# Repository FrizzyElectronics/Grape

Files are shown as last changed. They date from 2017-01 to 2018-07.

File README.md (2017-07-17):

# Grape

frizzyelectronics (http://frizzy.es)

Grape es un Arduino&trade; compatible de fabricacion y diseño español. Destaca frente a otras placas por su rapidez de conexionado y por no necesitar el uso de protoboard para realizar los proyectos.

## Rasgos destacados

  - Conexion micro-USB
  - Corriente max de salida (5V) 2A
  - Pines de conexión rápida
  - Interruptor de encendido-apagado
  - 8 pines analogicos
  - Compatible con los shields de Arduino&trade; y con Arduino&trade; IDE

Frizzy Grape  

## Documentacion 

* **/Hardware** - Archivos de diseño en KiCad e Eagle, esquema en PDF
* **/Production** - Gerbers, BOM
* **/Design** - Logos, SVG 

Licencia
-------------------

Este producto es  **open source**! 

Por favor, revisa el archivo [LICENSE.md](https://github.com/FrizzyElectronics/Grape/blob/master/License.md) para más información. 

Si tiene alguna duda acerca del uso de esta licencia contatanos a traves de  info@frizzy.es

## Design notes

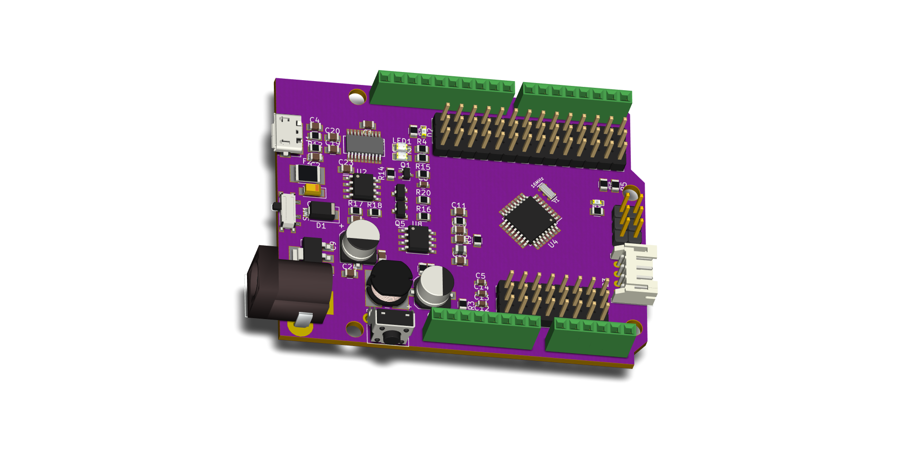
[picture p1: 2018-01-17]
Hardware/KiCad/images/Grape.png

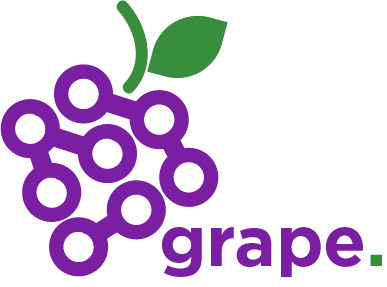
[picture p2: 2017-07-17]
Design/Frizzy Grape (color con texto).png

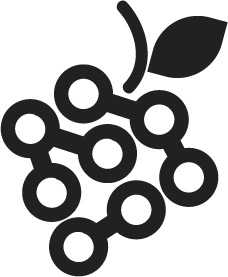
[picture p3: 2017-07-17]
Design/Frizzy Grape (negro sin texto).png

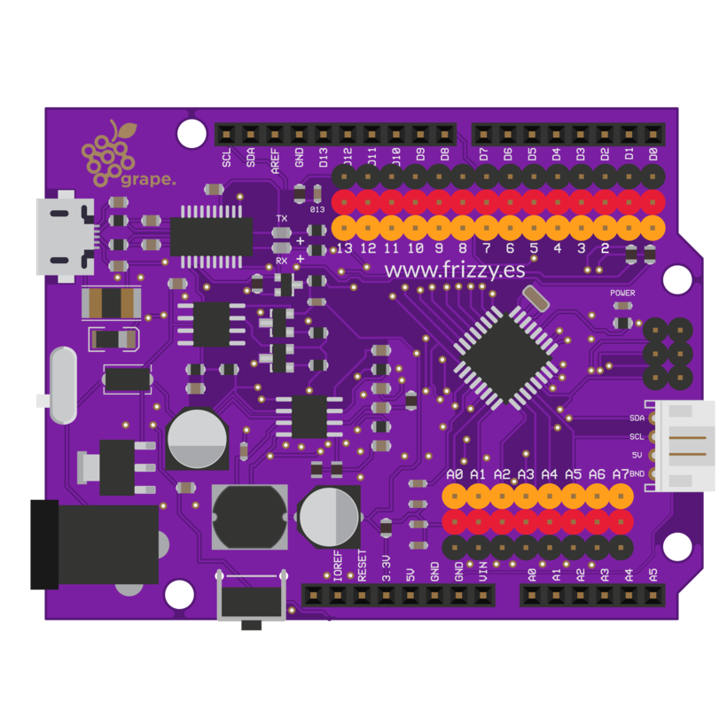
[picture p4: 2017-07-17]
Design/grape2-big.png

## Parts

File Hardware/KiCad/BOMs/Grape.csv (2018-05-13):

Id | Identificador | Empaquetado | Cantidad | Identificación | Suministrador y ref
1 | REF**,REF**,REF** | Fiducial_1mm_Dia_2mm_Outer | 3 | Fiducial_1mm_Dia_2mm_Outer
2 | J3 | ARDUINO_R3 | 1 | ARDUINO_R3
3 | REF*** | OSHW-Symbol_6.7x6mm_SilkScreen | 1 | OSHW-Symbol_6.7x6mm_SilkScreen
4 | C1,C2,C4,C10,C11,C15,C22,C23,C24 | C_0805 | 9 | 100nF
5 | C3 | CP_Tantalum_Case-A_EIA-3216-18_Reflow | 1 | 10nF
6 | C5,C6,C13 | C_0603 | 3 | 100nF
7 | C7,C9 | CP_Elec_6.3x5.3 | 2 | 100uF
8 | C8 | C_0805 | 1 | 3.3nF
9 | C12 | C_0603 | 1 | 1uF
10 | C14 | C_0603 | 1 | 10nF
11 | C16 | C_0805 | 1 | 10nF
12 | C19,C20 | C_0805 | 2 | 47pF
13 | D1 | D_SMA | 1 | MBRA140
14 | D2 | LED_0603 | 1 | YELLOW
15 | D4 | LED_0603 | 1 | PURPLE
16 | F2 | R_1812 | 1 | 500mA
17 | J19 | JACK_ALIM | 1 | POWER_JACKPTH
18 | L1 | L_Wuerth_WE-PD2-Typ-L | 1 | 10uH
19 | L2 | L_0805 | 1 | 60R 100M Ferrite
20 | LED1 | LED_0805 | 1 | RED
21 | LED2 | LED_0805 | 1 | GREEN
22 | P1,P2,P3,P4,P5,P6,P7,P8,P9,P10,P11,P12,P13,P14,P15,P16,P17,P18,P19,P20,P21,P22 | Pin_Header_Straight_1x03_Pitch2.54mm | 22 | CONN_01X03
23 | P23 | JST_PH_S4B-PH-K_04x2.00mm_Angled | 1 | I2C
24 | Q1 | SOT-323_SC-70 | 1 | 2N7002PW
25 | Q4,Q5 | SOT-23 | 2 | FDN340P
26 | R1,R2,R4,R5,R6,R8 | R_0805 | 6 | 1k
27 | R3,R14,R15,R16,R17,R18,R20 | R_0805 | 7 | 10k
28 | R7 | R_0805 | 1 | 5K6 1%
29 | R9 | R_0805 | 1 | 6.8k
30 | R10 | R_0805 | 1 | 1k 1%
31 | R11 | R_0805 | 1 | 100k
32 | R12,R13 | R_0805 | 2 | 27R
33 | S2 | SW_Tactile_SPST_Angled_PTS645Vx39-2LFS | 1 | RESET
34 | SW1 | SW_SPDT_PCM12 | 1 | SW_SPDT
35 | U1 | SSOP-20 | 1 | FT231XS
36 | U2 | SOIC-8_3.9x4.9mm_Pitch1.27mm | 1 | LM358
37 | U3 | SOT-223 | 1 | AMS1117-3.3
38 | U4 | TQFP-32_7x7mm_Pitch0.8mm | 1 | ATMEGA328P_TQFP
39 | U8 | HTSOP-8-1EP_3.9x4.9mm_Pitch1.27mm_ThermalVias_LargeCopper | 1 | MP2307SO
40 | Y1 | RESONATOR-SMD-3.2X1.3 | 1 | 16MHz
41 | REF**,REF**,REF**,REF**,REF**,REF**,REF**,REF**,REF**,REF**,REF**,REF**,REF** | VIA-0.6mm | 13 | VIA-0.6mm
42 | G*** | logo_grape | 1 | LOGO
43 | G*** | web | 1 | LOGO
44 | J1 | USB_Micro-B_Molex-105017-0001 | 1 | USB_MICROB
45 | G*** | web2 | 1 | LOGO

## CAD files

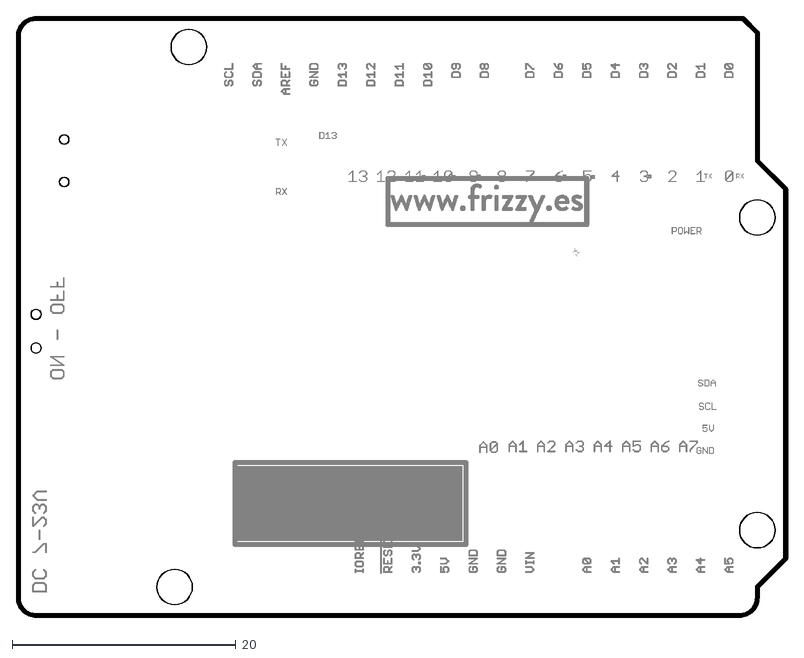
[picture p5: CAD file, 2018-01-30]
Hardware/Eagle/Grape.dxf
69.0 x 53.7

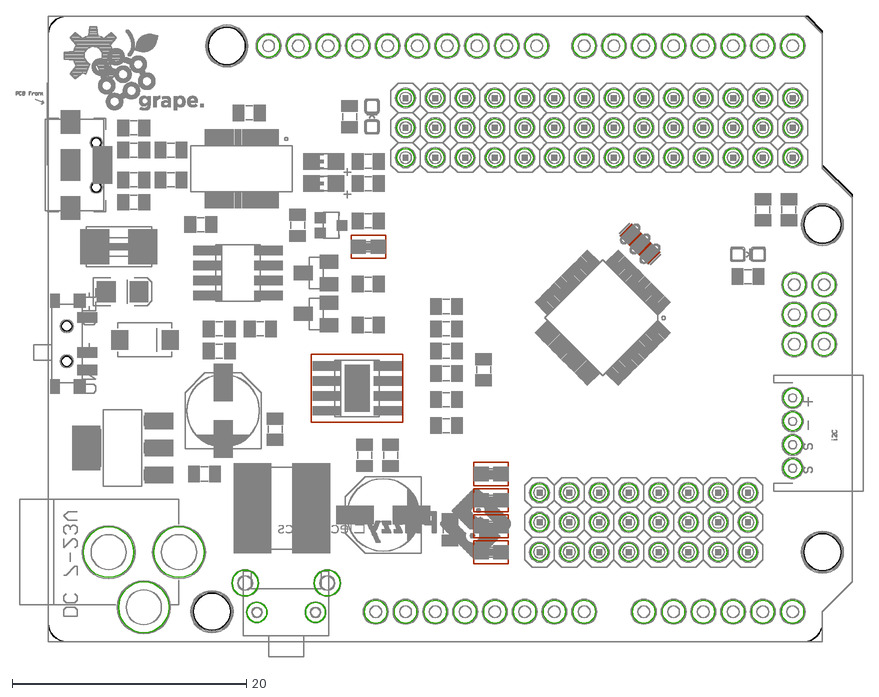
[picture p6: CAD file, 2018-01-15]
Hardware/Eagle/Grape3.dxf
72.2 x 54.7

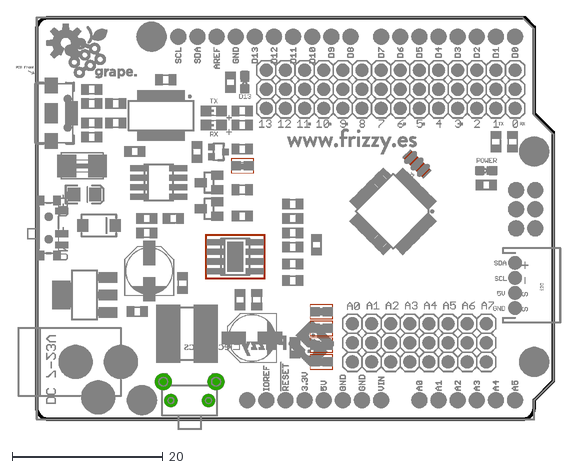
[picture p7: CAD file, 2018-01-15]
Hardware/Eagle/Grape2.dxf
72.4 x 55.0

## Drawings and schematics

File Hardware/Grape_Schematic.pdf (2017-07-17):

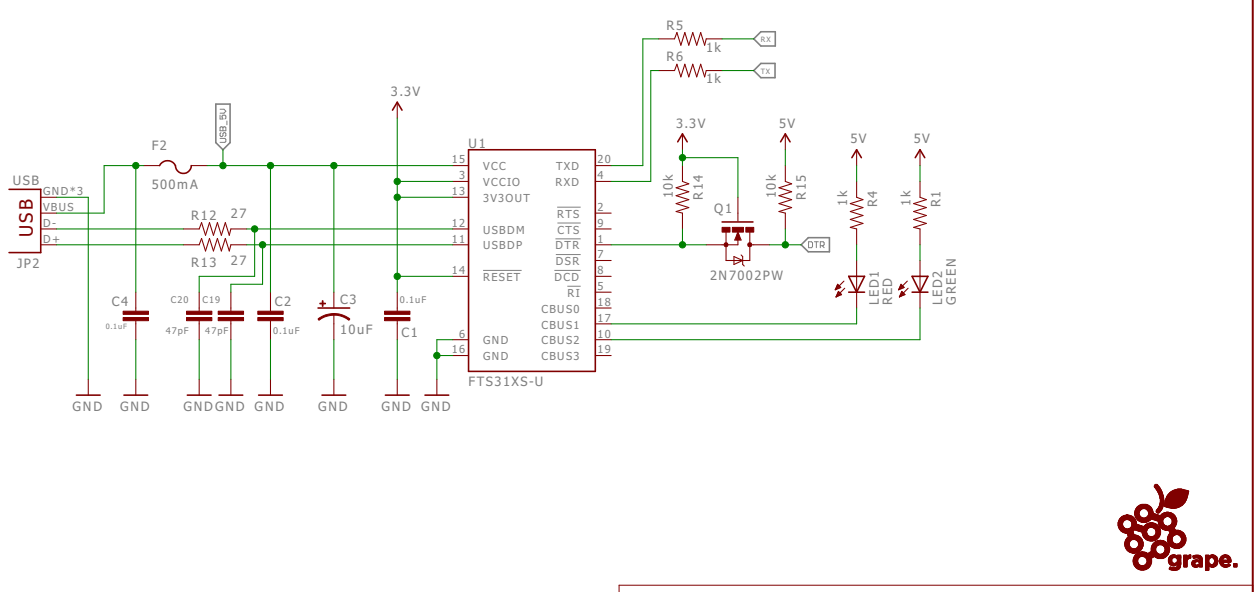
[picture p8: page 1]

Document Number: | REV:

Date: 17/07/2016 16:00 | Sheet: 1/4

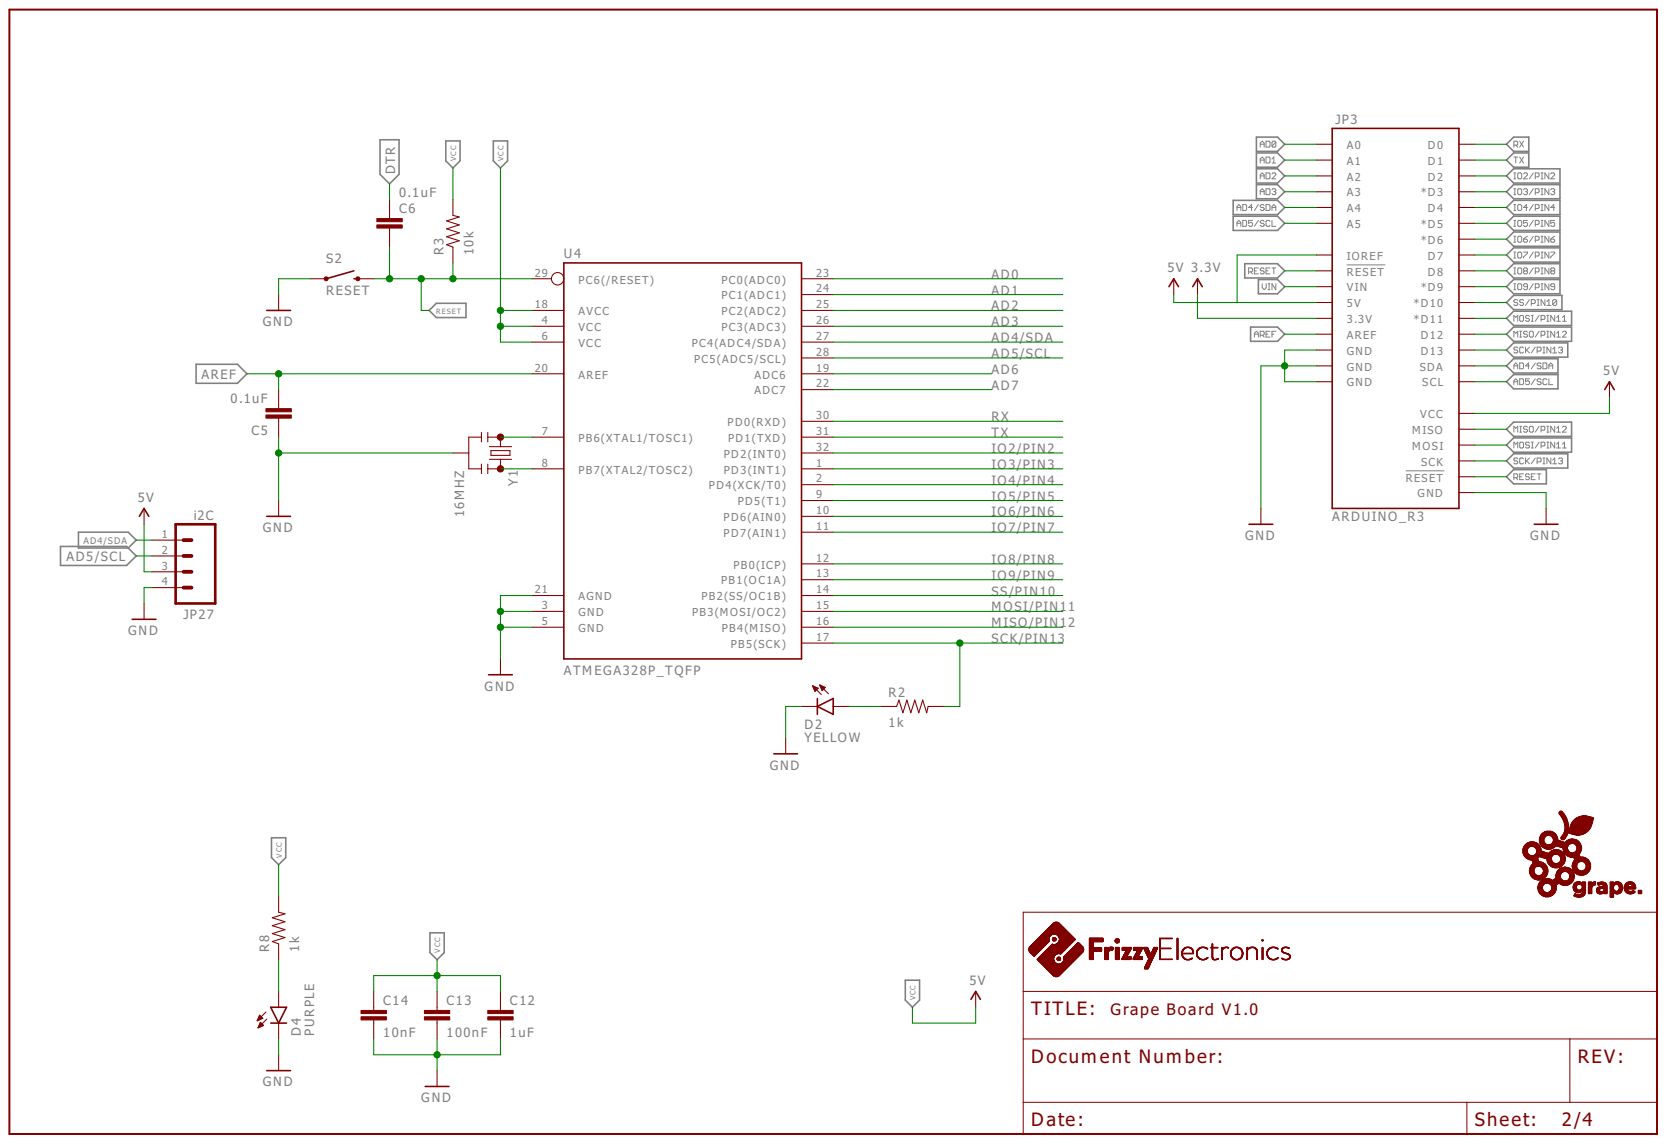
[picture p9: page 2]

IO8/PIN8
IO9/PIN9 SS/PIN10 MOSI/PIN11 MISO/PIN12 SCK/PIN13

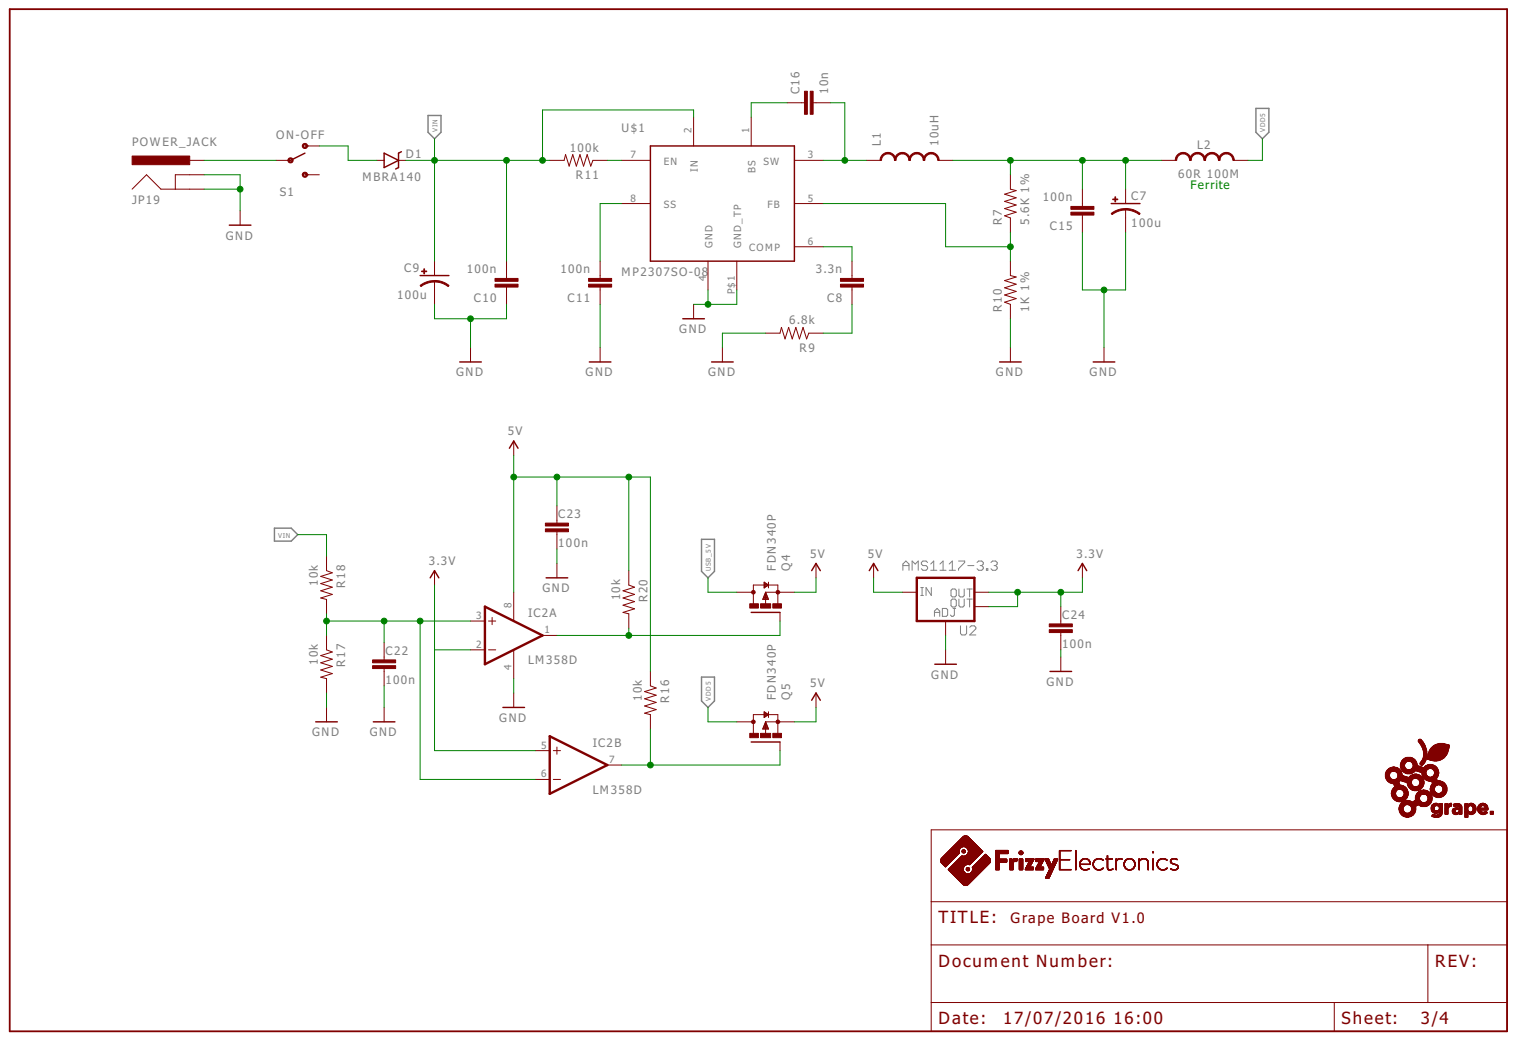
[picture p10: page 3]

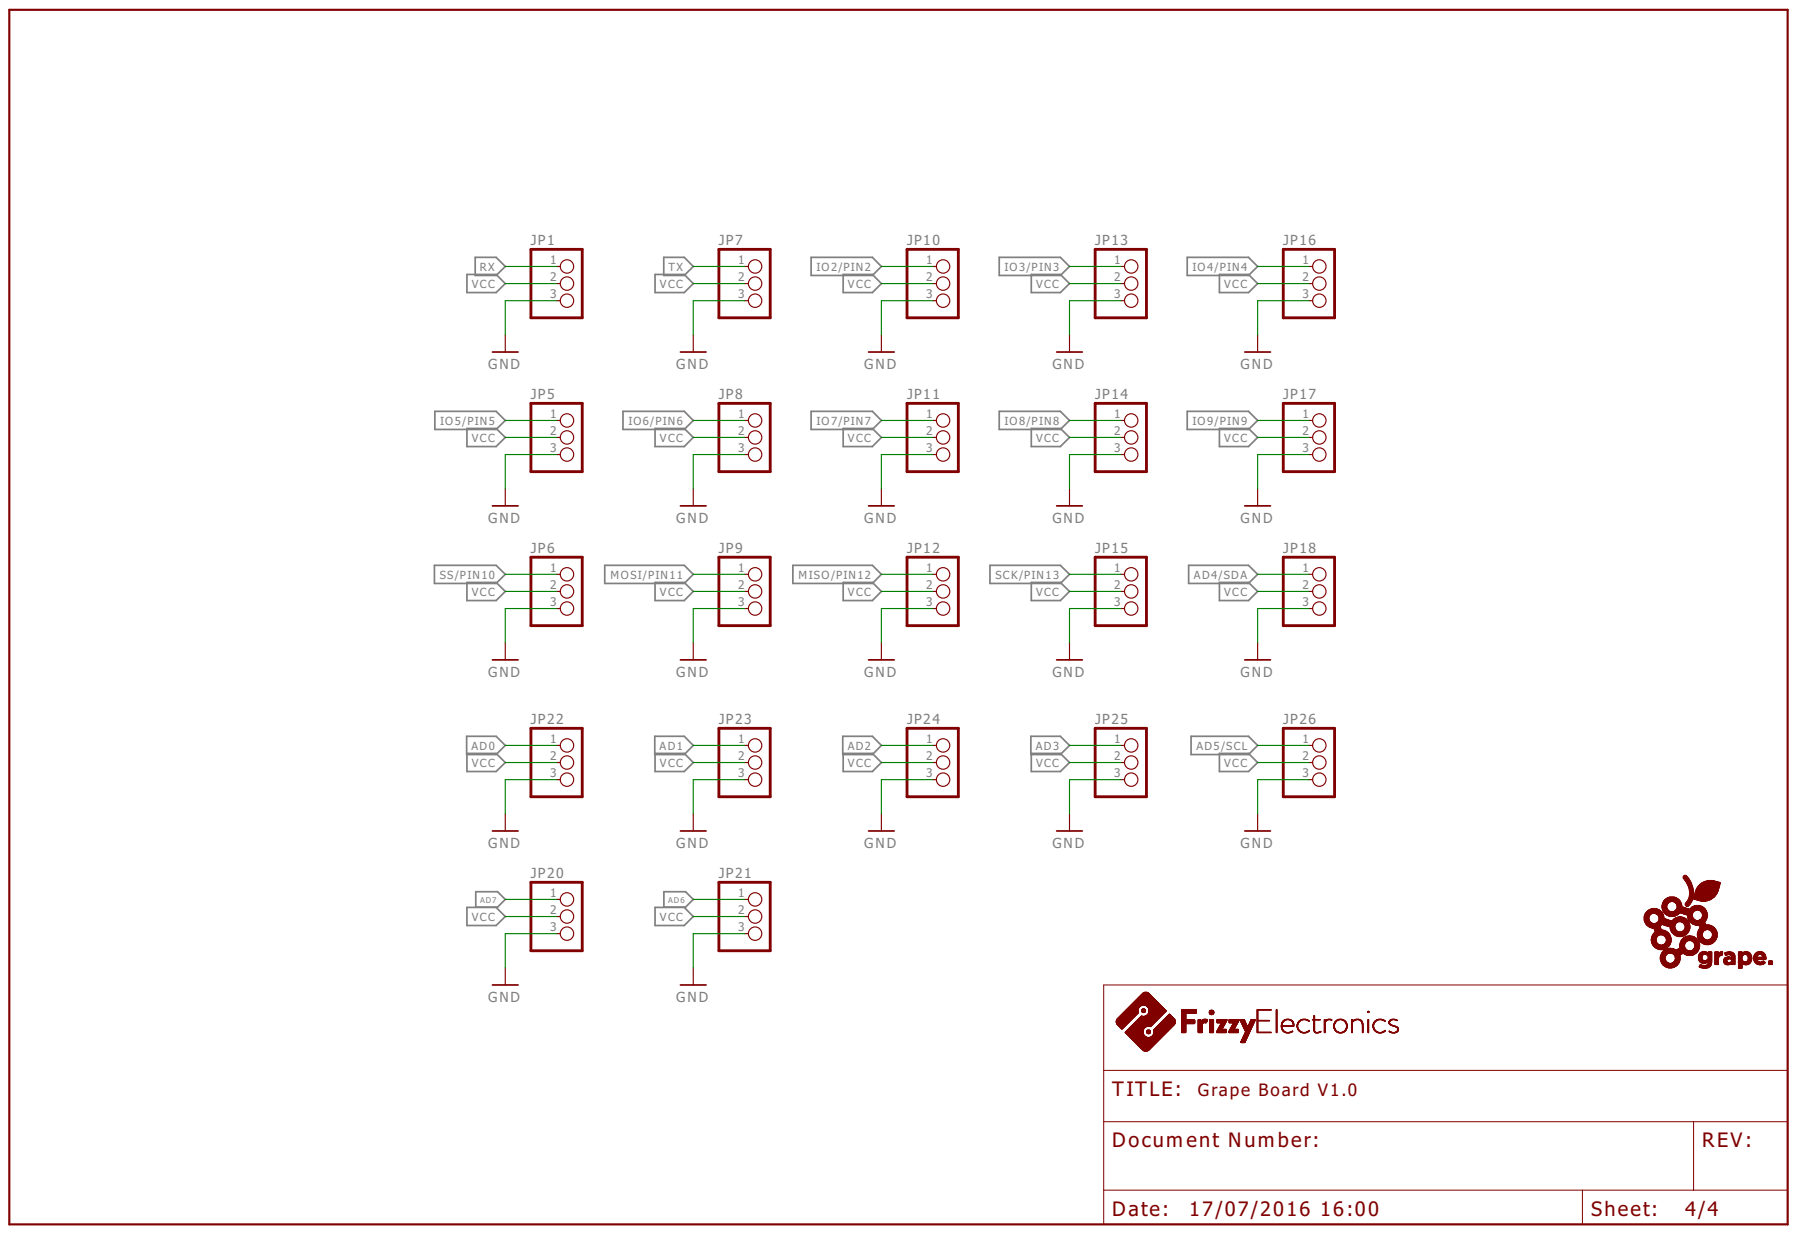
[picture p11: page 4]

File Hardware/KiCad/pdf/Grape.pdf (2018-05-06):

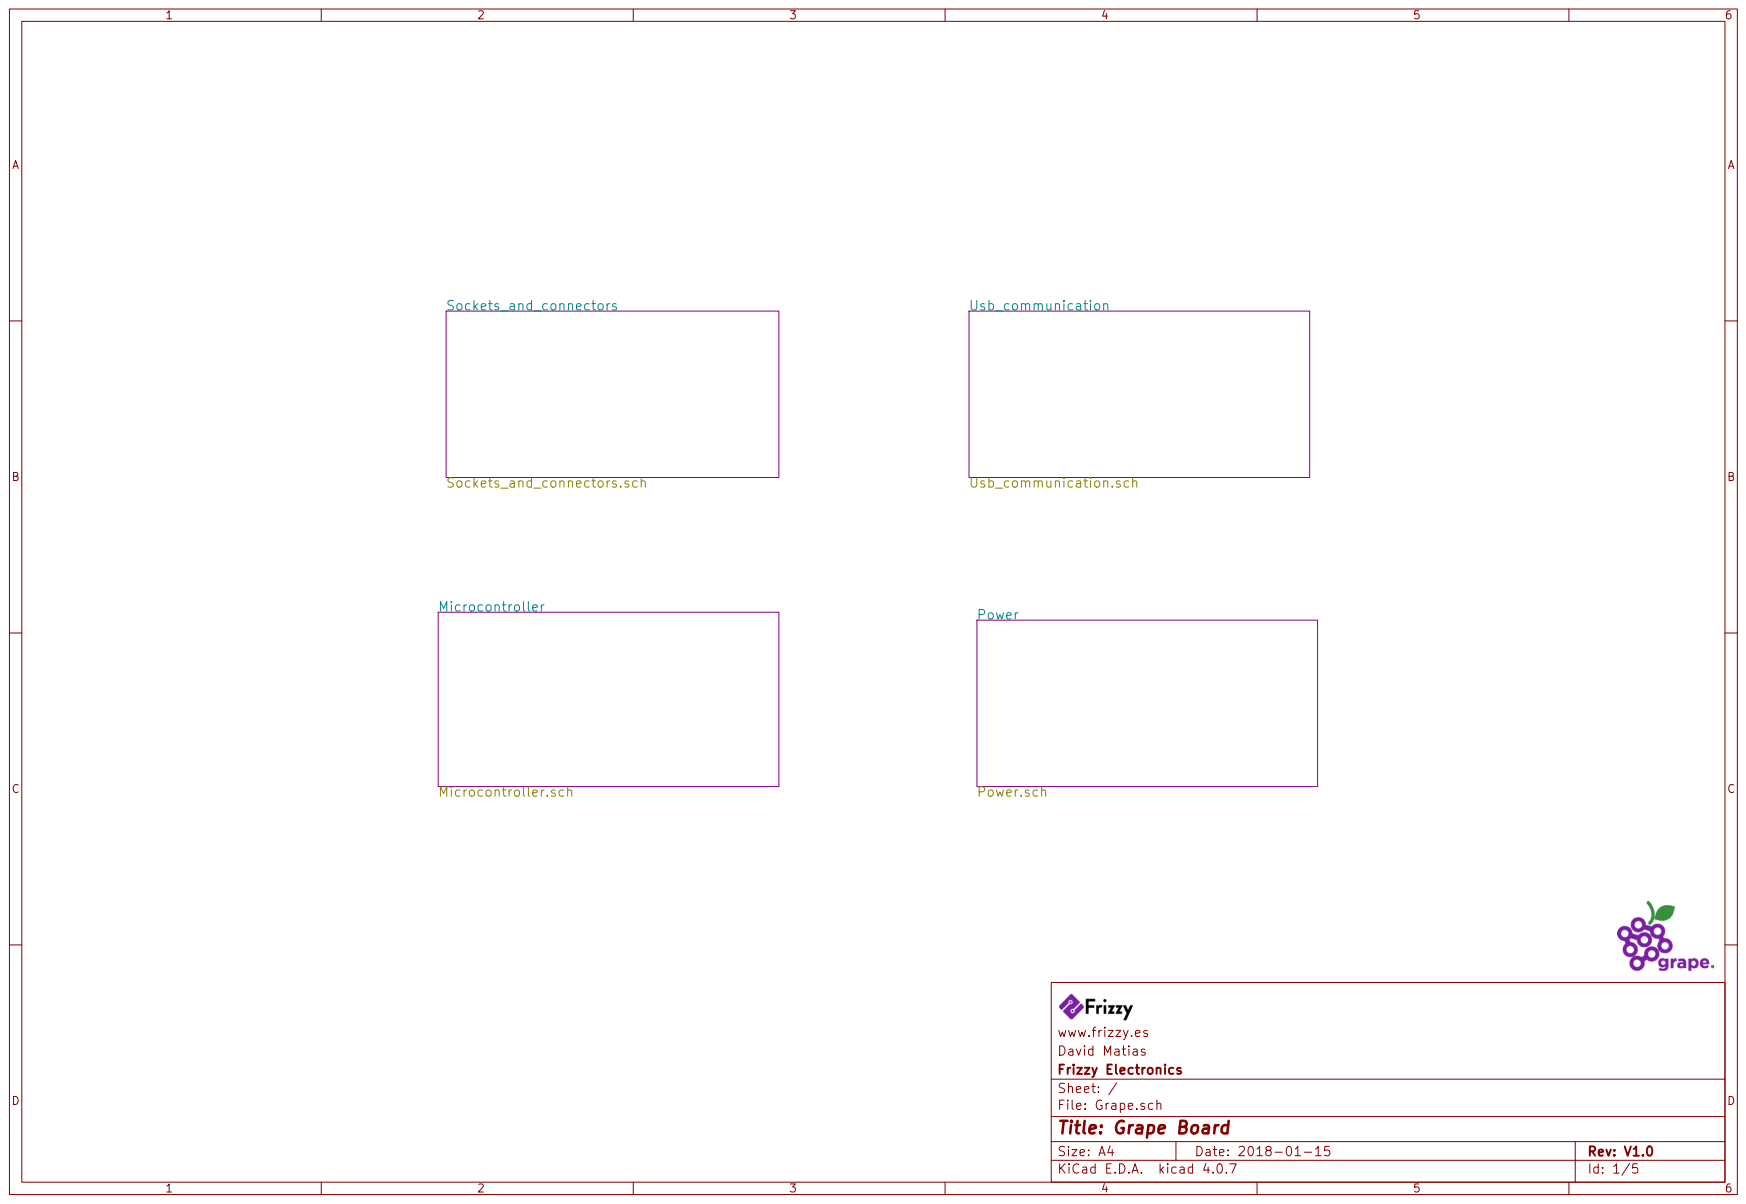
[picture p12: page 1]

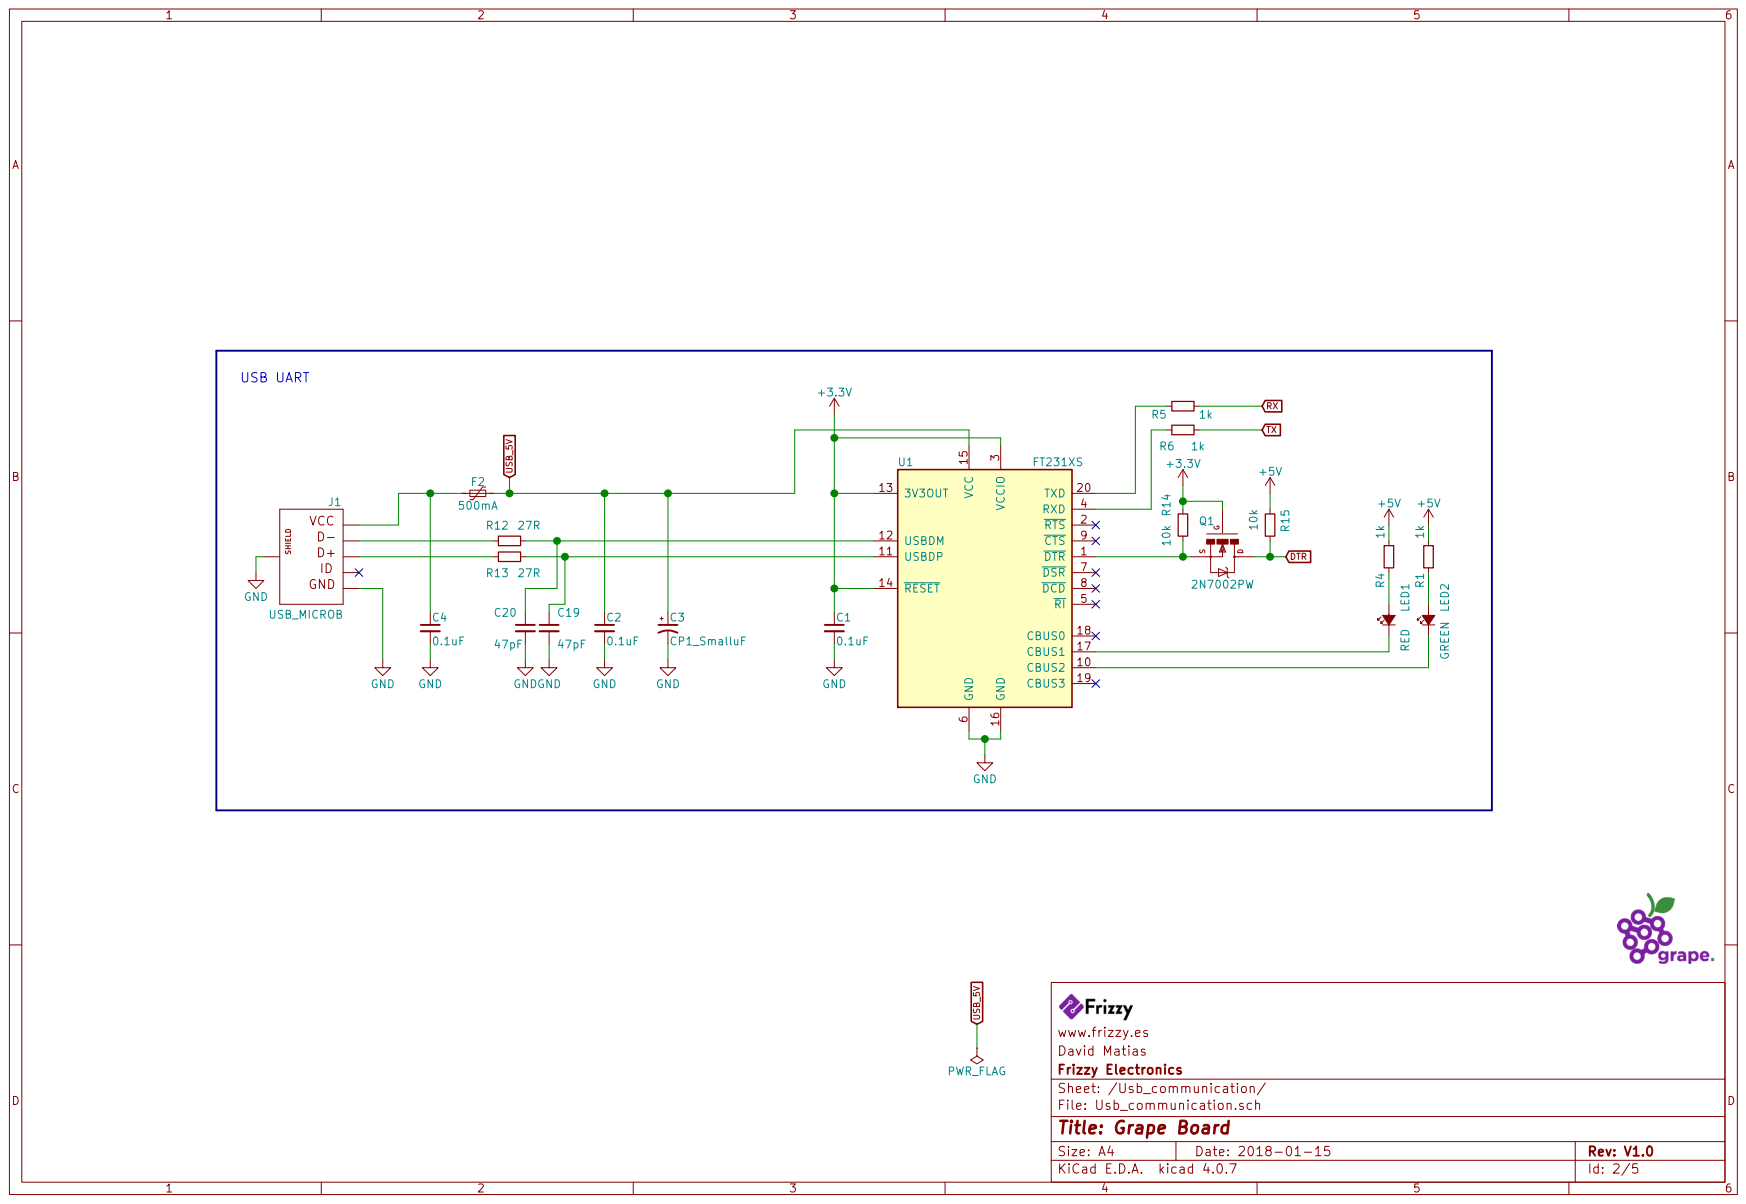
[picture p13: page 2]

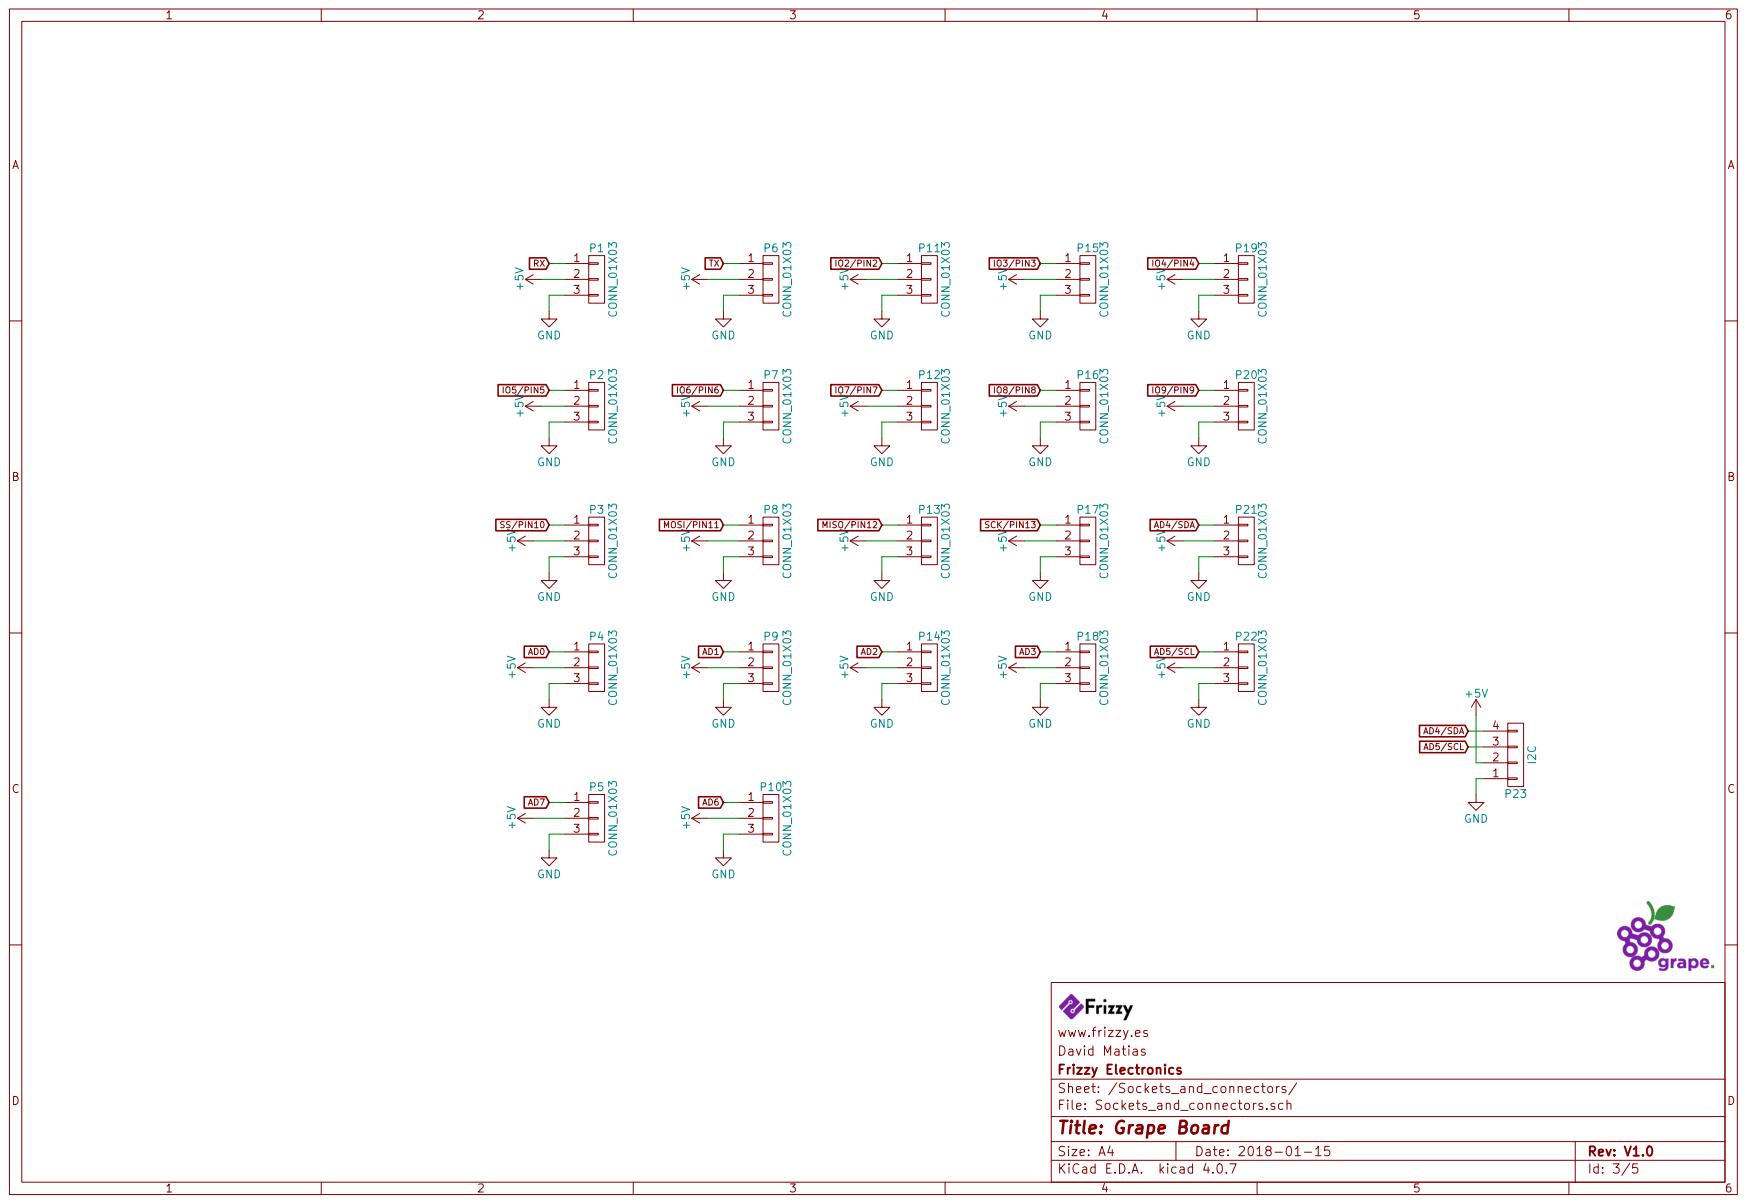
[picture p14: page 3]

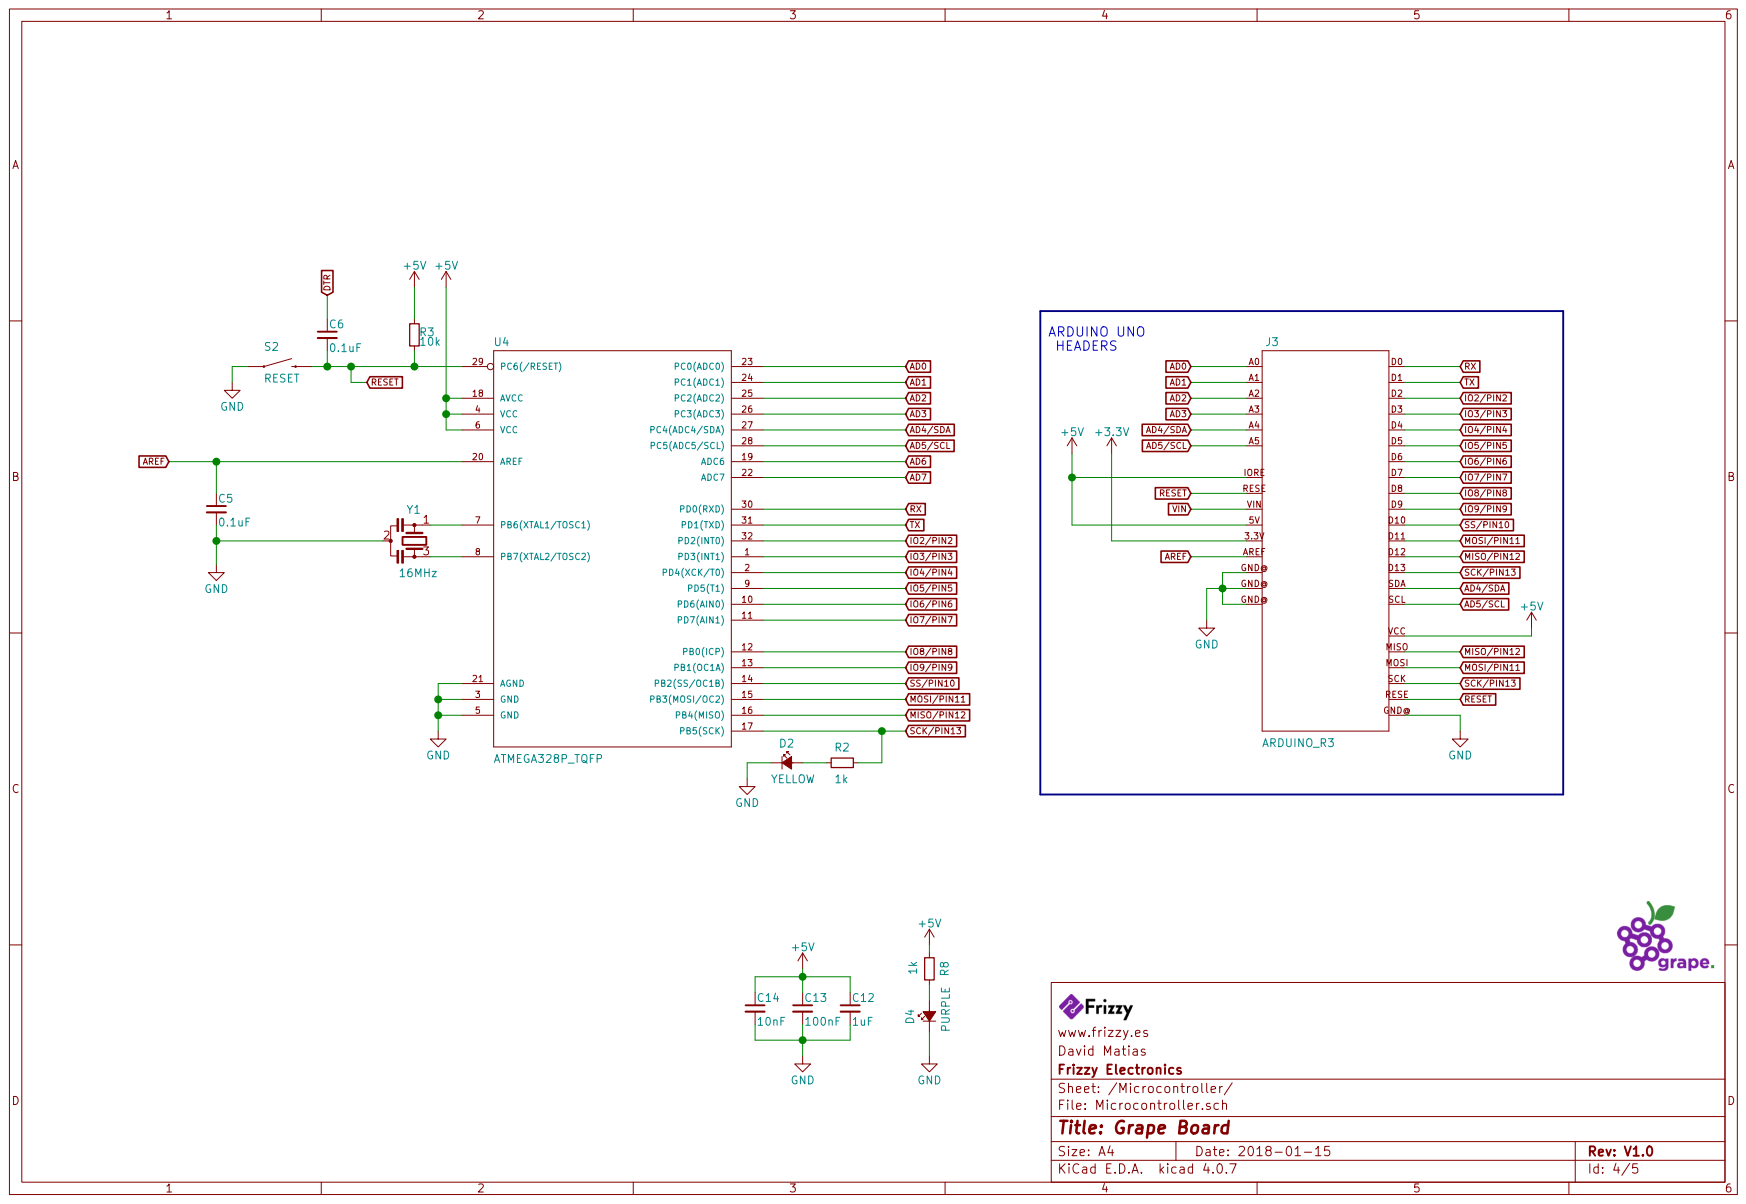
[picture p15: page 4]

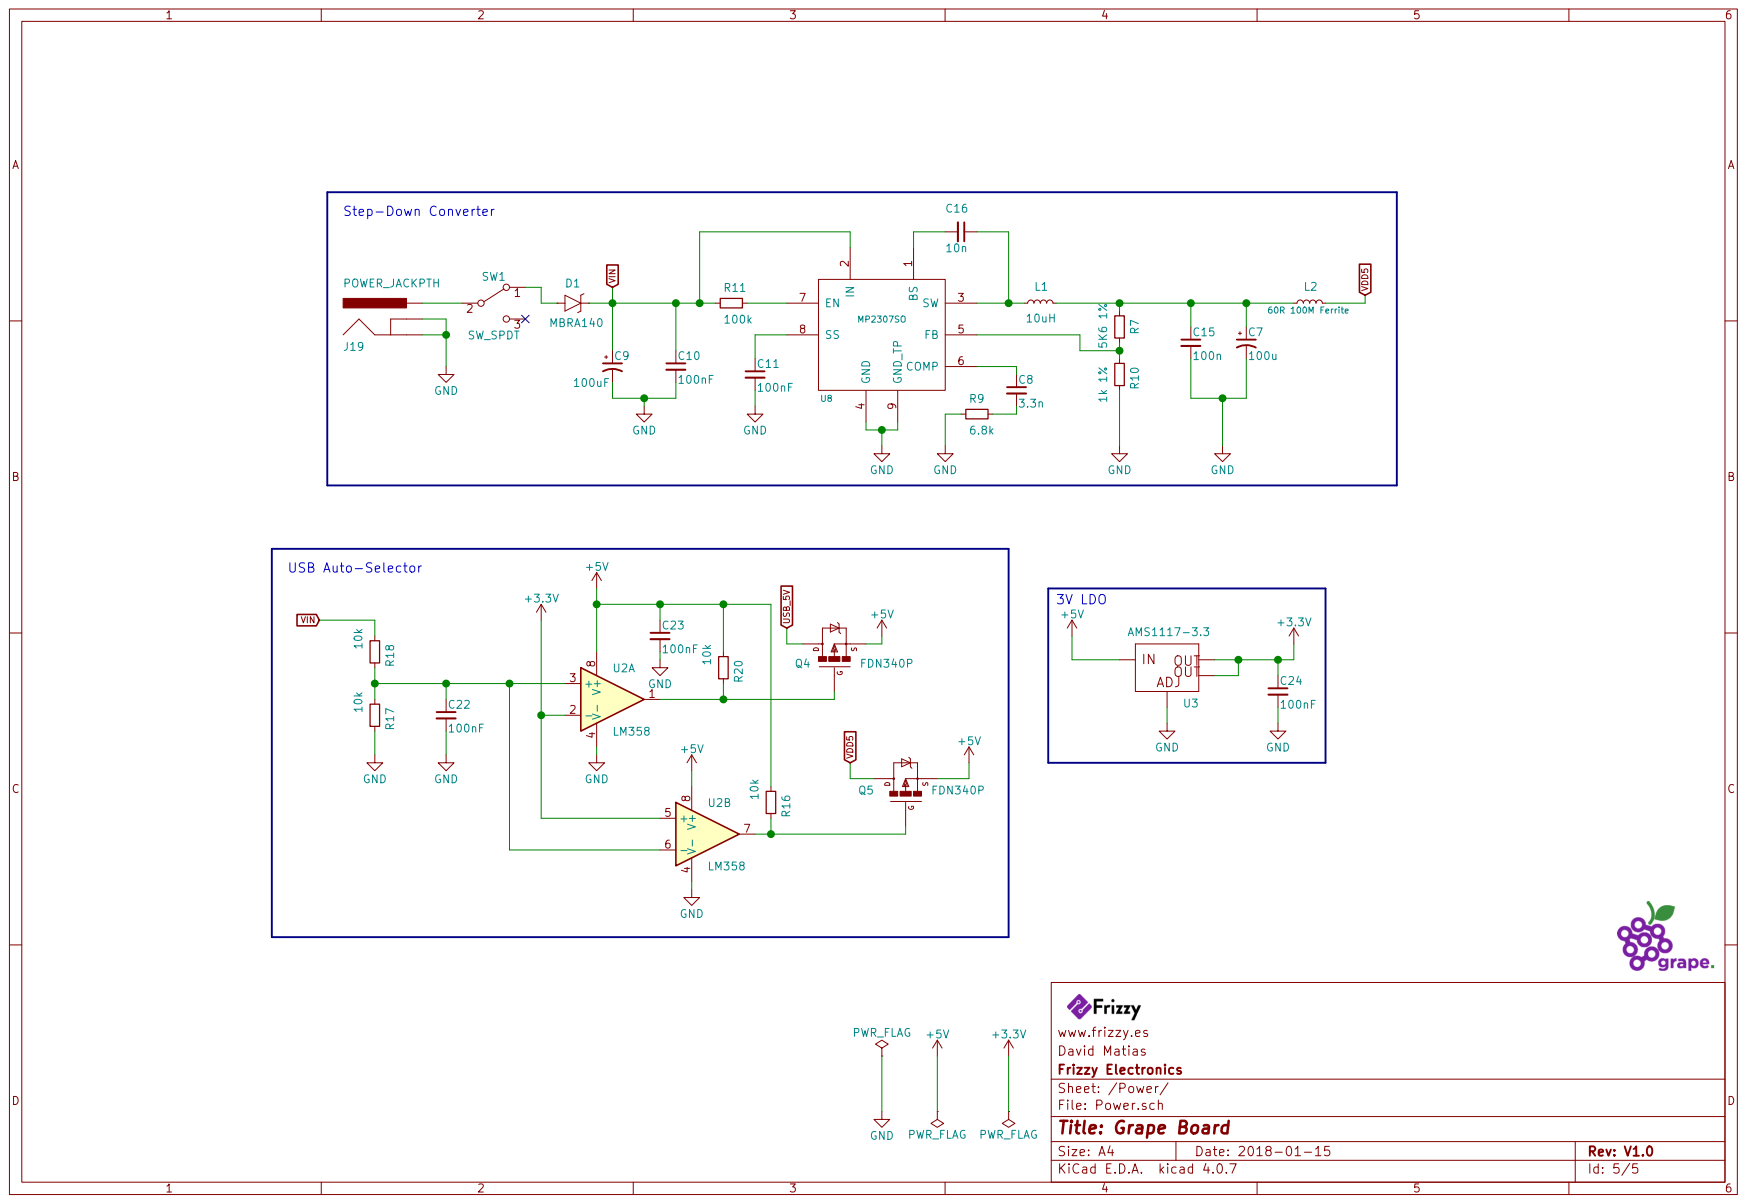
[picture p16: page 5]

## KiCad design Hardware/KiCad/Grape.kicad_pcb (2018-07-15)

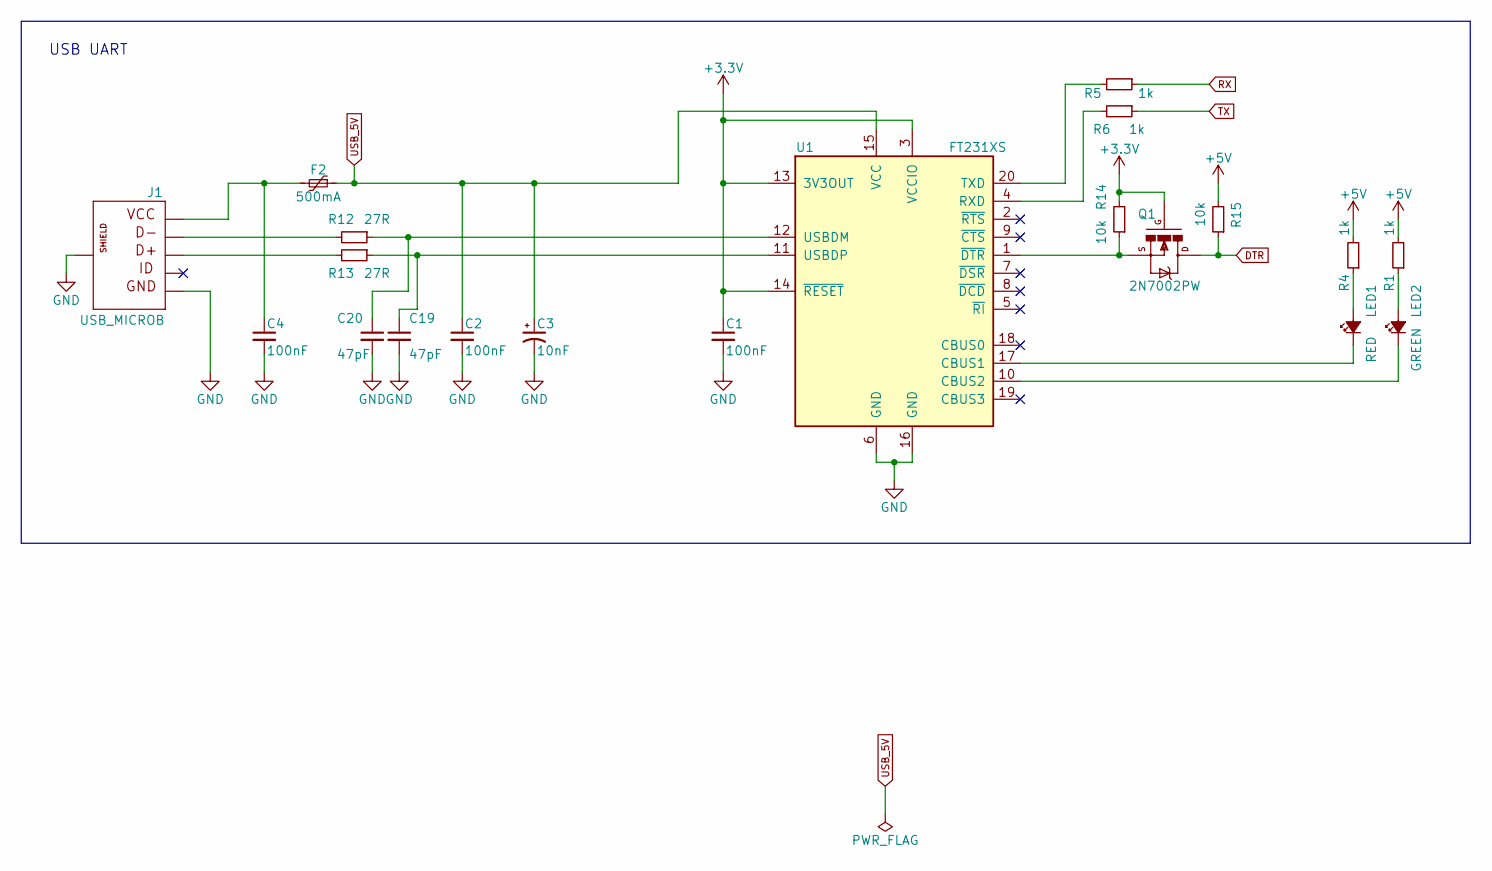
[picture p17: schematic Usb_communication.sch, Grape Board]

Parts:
C1, C2, C4: 100nF; C_0805
C3: 10nF; CP_Tantalum_Case-A_EIA-3216-18_Reflow
C19, C20: 47pF; C_0805
F2: 500mA; R_1812
J1: USB_MICROB; USB_Micro-B_Molex-105017-0001
LED1: RED; LED_0805
LED2: GREEN; LED_0805
Q1: 2N7002PW; SOT-323_SC-70
R1, R4, R5, R6: 1k; R_0805
R12, R13: 27R; R_0805
R14, R15: 10k; R_0805
U1: FT231XS; SSOP-20

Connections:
+3V3: C1.1, Q1.1 (G), R14.2, U1.3 (VCCIO), U1.13 (3V3OUT), U1.14 (~RESET); also elsewhere on the board
+5V: R1.2, R4.2, R15.2; also elsewhere on the board
DTR: Q1.3 (D), R15.1; also elsewhere on the board
GND: C1.2, C2.2, C3.2, C4.2, C19.2, C20.2, J1.5 (GND), J1.6 (SHIELD), U1.6 (GND), U1.16 (GND); also elsewhere on the board
unnamed: C4.1, F2.2, J1.1 (VCC)
unnamed: C19.1, R13.1, U1.11 (USBDP)
unnamed: C20.1, R12.1, U1.12 (USBDM)
unnamed: J1.2 (D-), R12.2
unnamed: J1.3 (D+), R13.2
unnamed: LED1.1 (K), U1.17 (CBUS1)
unnamed: LED1.2 (A), R4.1
unnamed: LED2.1 (K), U1.10 (CBUS2)
unnamed: LED2.2 (A), R1.1
unnamed: Q1.2 (S), R14.1, U1.1 (~DTR)
unnamed: R5.2, U1.20 (TXD)
unnamed: R6.2, U1.4 (RXD)
RX: R5.1; also elsewhere on the board
TX: R6.1; also elsewhere on the board
USB_5V: C2.1, C3.1, F2.1, U1.15 (VCC); also elsewhere on the board

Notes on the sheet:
USB UART

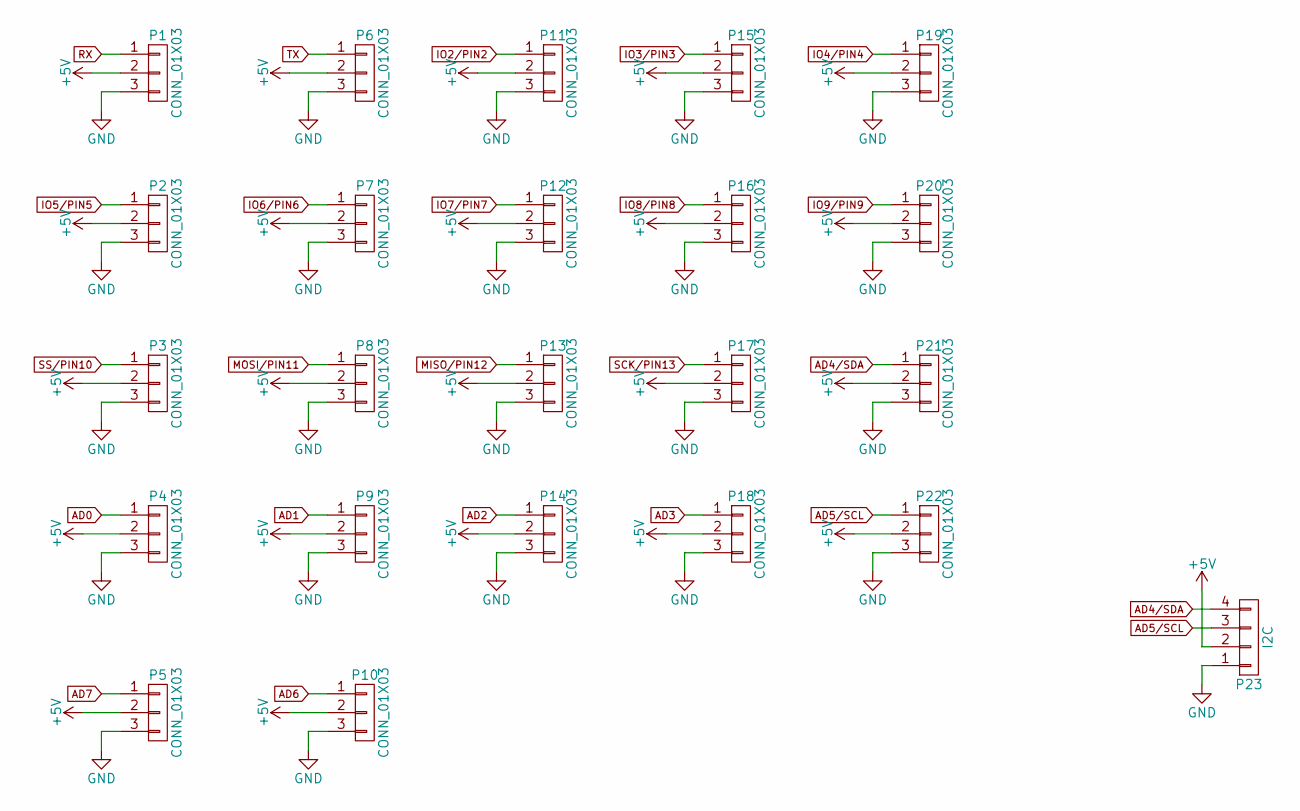
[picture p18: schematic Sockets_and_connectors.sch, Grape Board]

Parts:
P1, P2, P3, P4, P5, P6, P7, P8, P9, P10, P11, P12, P13, P14, P15, P16, P17, P18, P19, P20, P21, P22: CONN_01X03; Pin_Header_Straight_1x03_Pitch2.54mm
P23: I2C; JST_PH_S4B-PH-K_04x2.00mm_Angled

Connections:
+5V: P1.2, P2.2, P3.2, P4.2, P5.2, P6.2, P7.2, P8.2, P9.2, P10.2, P11.2, P12.2, P13.2, P14.2, P15.2, P16.2, P17.2, P18.2, P19.2, P20.2, P21.2, P22.2, P23.2; also elsewhere on the board
AD0: P4.1; also elsewhere on the board
AD1: P9.1; also elsewhere on the board
AD2: P14.1; also elsewhere on the board
AD3: P18.1; also elsewhere on the board
AD4/SDA: P21.1, P23.4; also elsewhere on the board
AD5/SCL: P22.1, P23.3; also elsewhere on the board
AD6: P10.1; also elsewhere on the board
AD7: P5.1; also elsewhere on the board
GND: P1.3, P2.3, P3.3, P4.3, P5.3, P6.3, P7.3, P8.3, P9.3, P10.3, P11.3, P12.3, P13.3, P14.3, P15.3, P16.3, P17.3, P18.3, P19.3, P20.3, P21.3, P22.3, P23.1; also elsewhere on the board
IO2/PIN2: P11.1; also elsewhere on the board
IO3/PIN3: P15.1; also elsewhere on the board
IO4/PIN4: P19.1; also elsewhere on the board
IO5/PIN5: P2.1; also elsewhere on the board
IO6/PIN6: P7.1; also elsewhere on the board
IO7/PIN7: P12.1; also elsewhere on the board
IO8/PIN8: P16.1; also elsewhere on the board
IO9/PIN9: P20.1; also elsewhere on the board
MISO/PIN12: P13.1; also elsewhere on the board
MOSI/PIN11: P8.1; also elsewhere on the board
RX: P1.1; also elsewhere on the board
SCK/PIN13: P17.1; also elsewhere on the board
SS/PIN10: P3.1; also elsewhere on the board
TX: P6.1; also elsewhere on the board

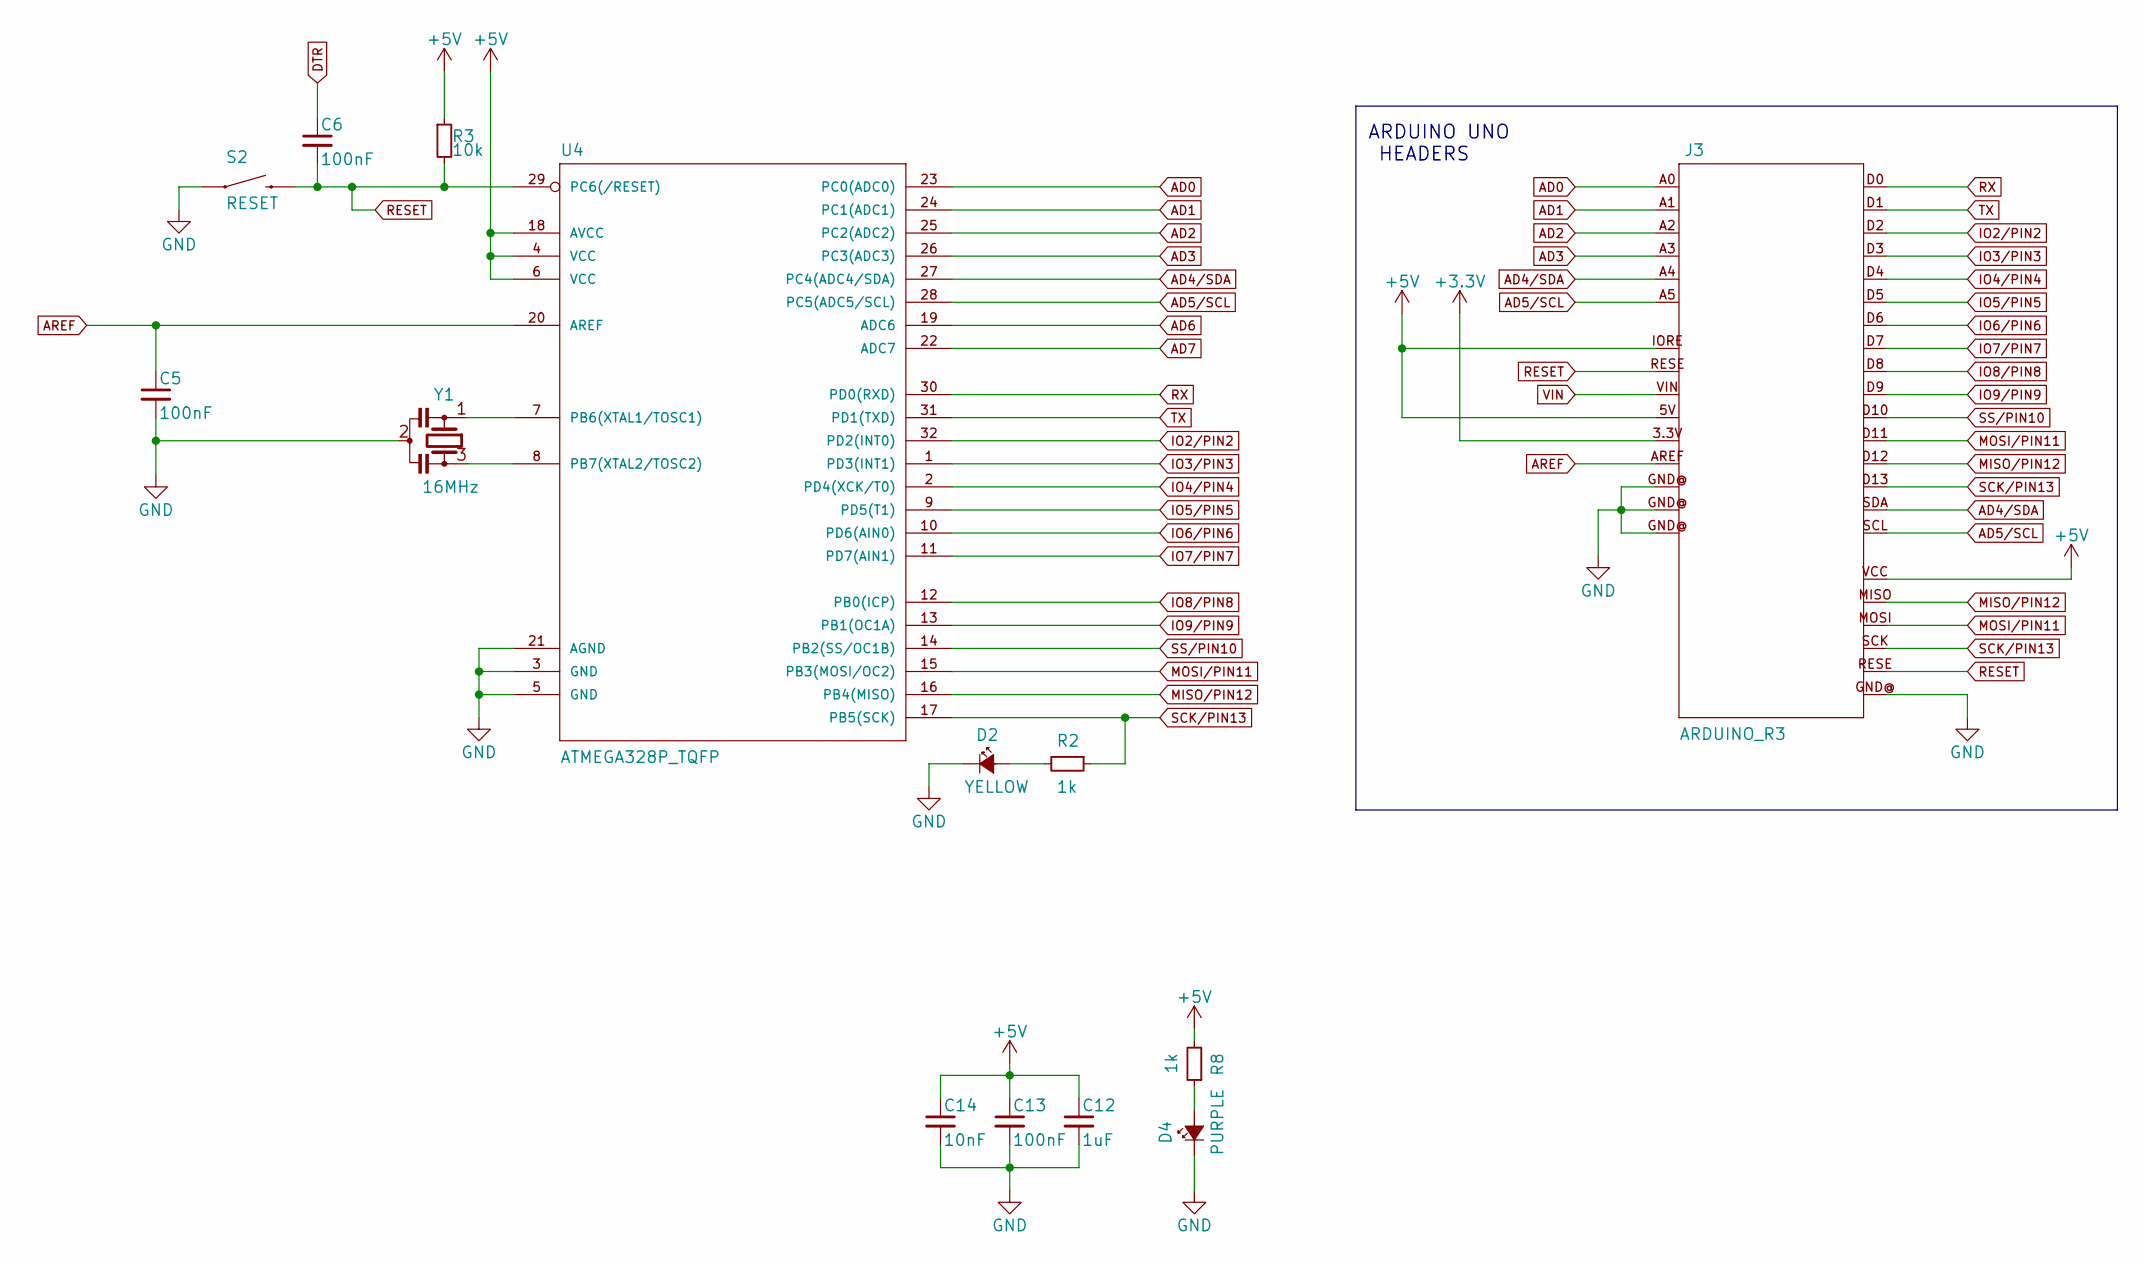
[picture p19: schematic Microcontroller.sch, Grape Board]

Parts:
C5, C6, C13: 100nF; C_0603
C12: 1uF; C_0603
C14: 10nF; C_0603
D2: YELLOW; LED_0603
D4: PURPLE; LED_0603
J3: ARDUINO_R3
R2, R8: 1k; R_0805
R3: 10k; R_0805
S2: RESET; SW_Tactile_SPST_Angled_PTS645Vx39-2LFS
U4: ATMEGA328P_TQFP; TQFP-32_7x7mm_Pitch0.8mm
Y1: 16MHz; RESONATOR-SMD-3.2X1.3

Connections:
+3V3: J3.3.3V; also elsewhere on the board
+5V: C12.1, C13.1, C14.1, J3.5V, J3.IORE (IOREF), J3.VCC, R3.1, R8.2, U4.4 (VCC), U4.6 (VCC), U4.18 (AVCC); also elsewhere on the board
AD0: J3.A0, U4.23 (PC0(ADC0)); also elsewhere on the board
AD1: J3.A1, U4.24 (PC1(ADC1)); also elsewhere on the board
AD2: J3.A2, U4.25 (PC2(ADC2)); also elsewhere on the board
AD3: J3.A3, U4.26 (PC3(ADC3)); also elsewhere on the board
AD4/SDA: J3.A4, J3.SDA, U4.27 (PC4(ADC4/SDA)); also elsewhere on the board
AD5/SCL: J3.A5, J3.SCL, U4.28 (PC5(ADC5/SCL)); also elsewhere on the board
AD6: U4.19 (ADC6); also elsewhere on the board
AD7: U4.22 (ADC7); also elsewhere on the board
AREF: C5.1, J3.AREF, U4.20 (AREF)
DTR: C6.1; also elsewhere on the board
GND: C5.2, C12.2, C13.2, C14.2, D2.1 (K), D4.1 (K), J3.GND@ (GND), S2.1, U4.3 (GND), U4.5 (GND), U4.21 (AGND), Y1.2; also elsewhere on the board
IO2/PIN2: J3.D2, U4.32 (PD2(INT0)); also elsewhere on the board
IO3/PIN3: J3.D3 (*D3), U4.1 (PD3(INT1)); also elsewhere on the board
IO4/PIN4: J3.D4, U4.2 (PD4(XCK/T0)); also elsewhere on the board
IO5/PIN5: J3.D5 (*D5), U4.9 (PD5(T1)); also elsewhere on the board
IO6/PIN6: J3.D6 (*D6), U4.10 (PD6(AIN0)); also elsewhere on the board
IO7/PIN7: J3.D7, U4.11 (PD7(AIN1)); also elsewhere on the board
IO8/PIN8: J3.D8, U4.12 (PB0(ICP)); also elsewhere on the board
IO9/PIN9: J3.D9 (*D9), U4.13 (PB1(OC1A)); also elsewhere on the board
MISO/PIN12: J3.D12, J3.MISO, U4.16 (PB4(MISO)); also elsewhere on the board
MOSI/PIN11: J3.D11 (*D11), J3.MOSI, U4.15 (PB3(MOSI/OC2)); also elsewhere on the board
unnamed: D2.2 (A), R2.2
unnamed: D4.2 (A), R8.1
unnamed: U4.7 (PB6(XTAL1/TOSC1)), Y1.1
unnamed: U4.8 (PB7(XTAL2/TOSC2)), Y1.3
RESET: C6.2, J3.RESE (!RESET!), R3.2, S2.2, U4.29 (PC6(/RESET))
RX: J3.D0, U4.30 (PD0(RXD)); also elsewhere on the board
SCK/PIN13: J3.D13, J3.SCK, R2.1, U4.17 (PB5(SCK)); also elsewhere on the board
SS/PIN10: J3.D10 (*D10), U4.14 (PB2(SS/OC1B)); also elsewhere on the board
TX: J3.D1, U4.31 (PD1(TXD)); also elsewhere on the board
VIN: J3.VIN; also elsewhere on the board

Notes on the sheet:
ARDUINO UNO HEADERS

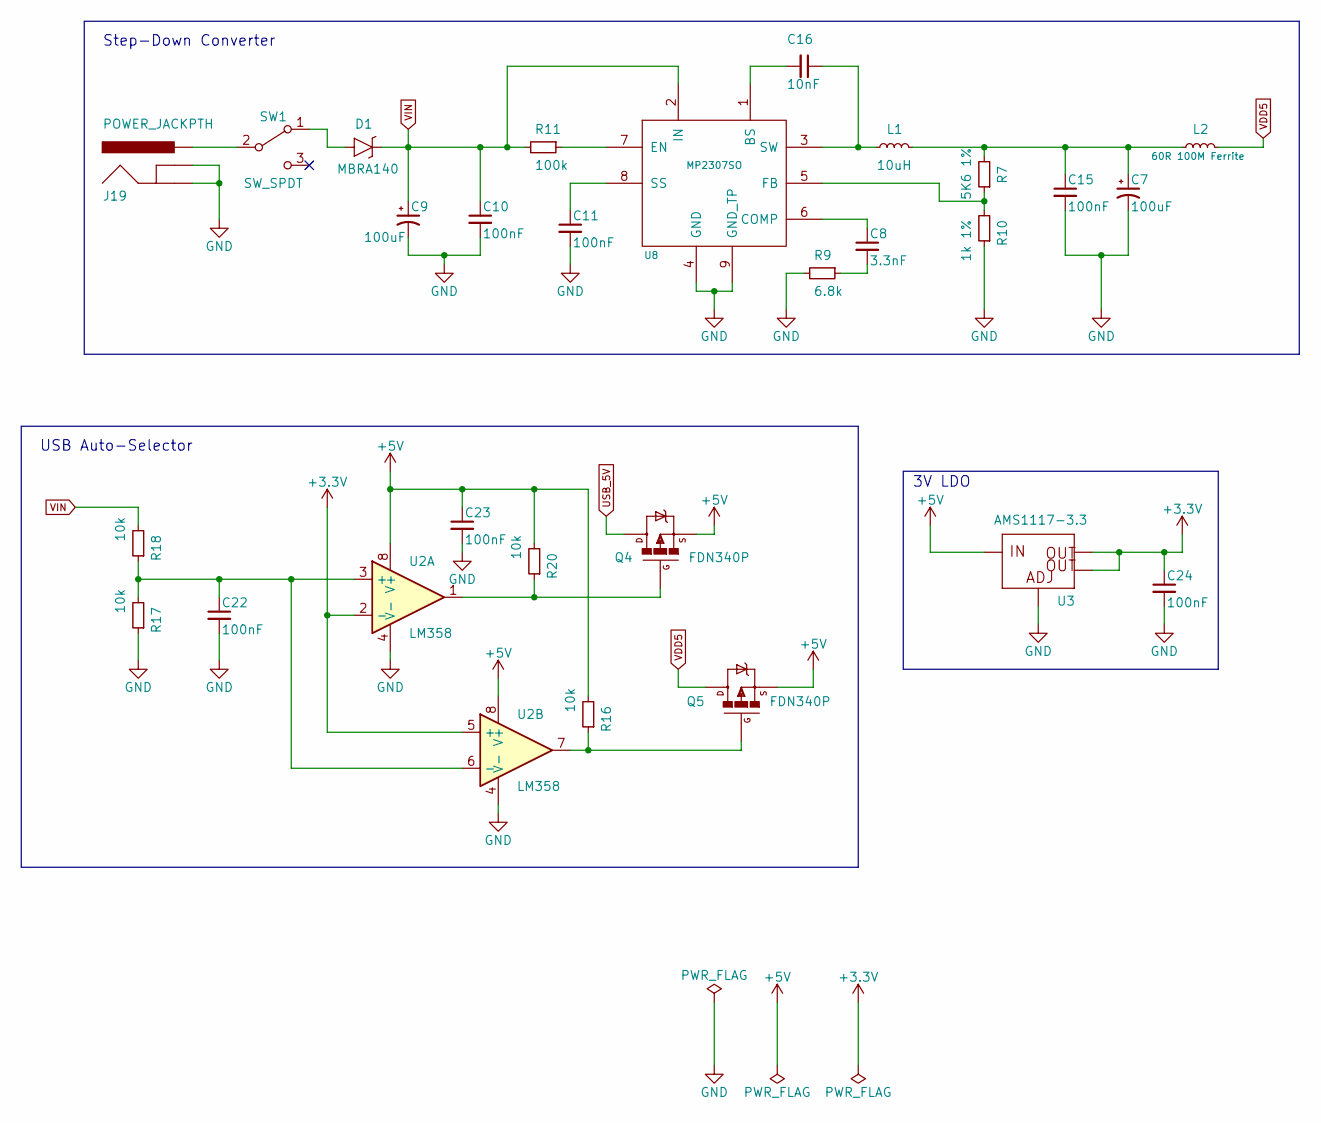
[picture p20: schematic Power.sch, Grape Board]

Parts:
C7, C9: 100uF; CP_Elec_6.3x5.3
C8: 3.3nF; C_0805
C10, C11, C15, C22, C23, C24: 100nF; C_0805
C16: 10nF; C_0805
D1: MBRA140; D_SMA
J19: POWER_JACKPTH; JACK_ALIM
L1: 10uH; L_Wuerth_WE-PD2-Typ-L
L2: 60R 100M Ferrite; L_0805
Q4, Q5: FDN340P; SOT-23
R7: 5K6 1%; R_0805
R9: 6.8k; R_0805
R10: 1k 1%; R_0805
R11: 100k; R_0805
R16, R17, R18, R20: 10k; R_0805
SW1: SW_SPDT; SW_SPDT_PCM12
U2: LM358; SOIC-8_3.9x4.9mm_Pitch1.27mm
U3: AMS1117-3.3; SOT-223
U8: MP2307SO; HTSOP-8-1EP_3.9x4.9mm_Pitch1.27mm_ThermalVias_LargeCopper

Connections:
+3V3: C24.1, U2.2 (-), U2.5 (+), U3.2 (OUT), U3.4 (OUT); also elsewhere on the board
+5V: C23.1, Q4.2 (S), Q5.2 (S), R16.2, R20.2, U2.8 (V+), U3.3 (IN); also elsewhere on the board
GND: C7.2, C9.2, C10.2, C11.2, C15.2, C22.2, C23.2, C24.2, J19.2 (GNDBREAK), J19.3 (GND), R9.2, R10.1, R17.1, U2.4 (V-), U3.1 (ADJ), U8.4 (GND), U8.9 (GND_TP); also elsewhere on the board
unnamed: C8.1, U8.6 (COMP)
unnamed: C8.2, R9.1
unnamed: C11.1, U8.8 (SS)
unnamed: C7.1, C15.1, L1.2, L2.1, R7.2
unnamed: C16.1, L1.1, U8.3 (SW)
unnamed: C16.2, U8.1 (BS)
unnamed: C22.1, R17.2, R18.1, U2.3 (+), U2.6 (-)
unnamed: D1.2 (A), SW1.1 (A)
unnamed: J19.1 (PWR), SW1.2 (B)
unnamed: Q4.1 (G), R20.1, U2.1
unnamed: Q5.1 (G), R16.1, U2.7
unnamed: R7.1, R10.2, U8.5 (FB)
unnamed: R11.1, U8.7 (EN)
USB_5V: Q4.3 (D); also elsewhere on the board
VDD5: L2.2, Q5.3 (D)
VIN: C9.1, C10.1, D1.1 (C), R11.2, R18.2, U8.2 (IN); also elsewhere on the board

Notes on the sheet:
Step-Down Converter
USB Auto-Selector
3V LDO

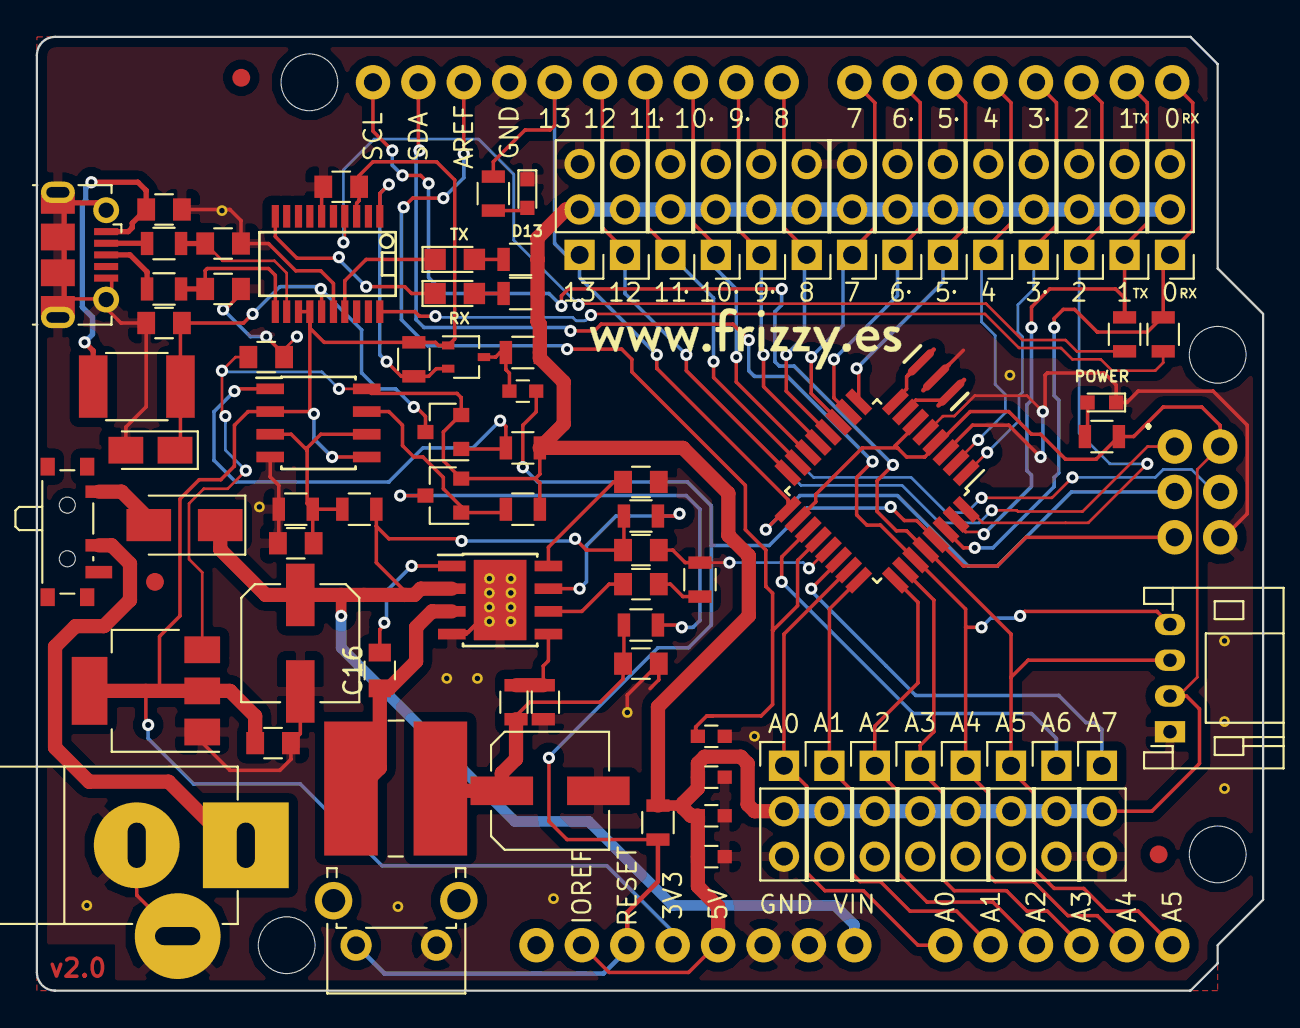
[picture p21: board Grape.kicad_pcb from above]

Board: 2 copper layers, 68.6 x 53.3 mm, 85 parts (0 on the bottom side), 60 nets.

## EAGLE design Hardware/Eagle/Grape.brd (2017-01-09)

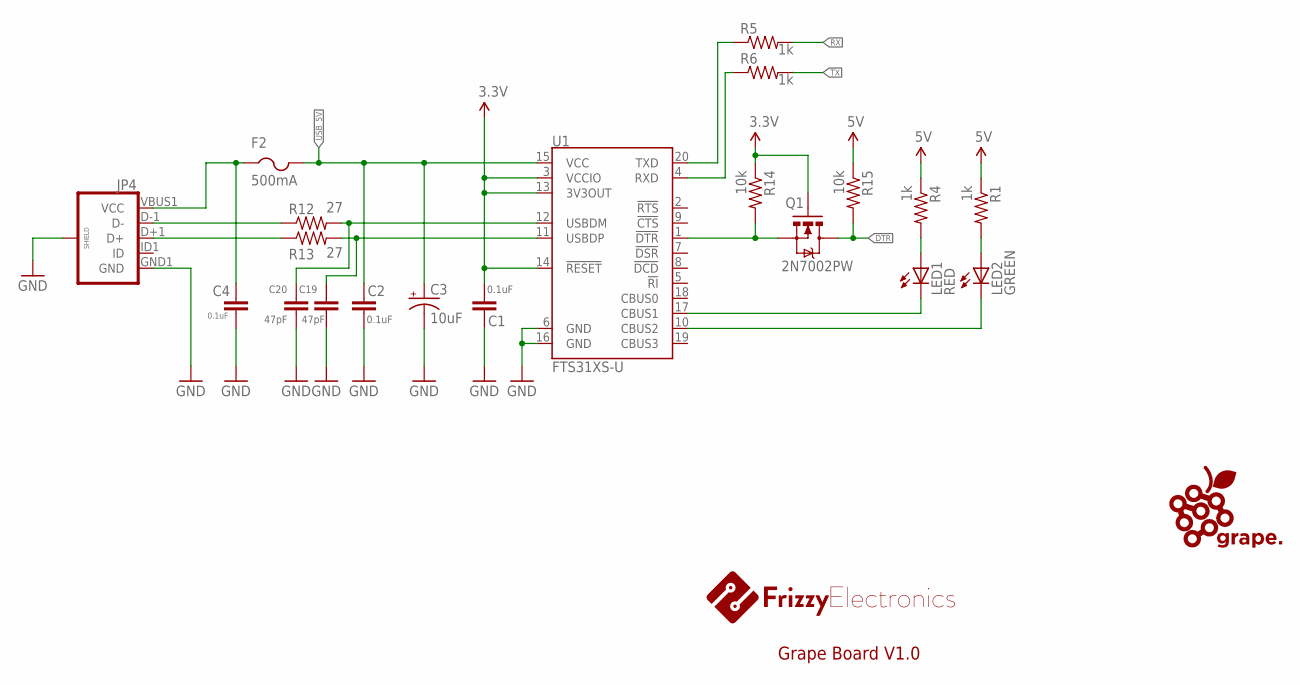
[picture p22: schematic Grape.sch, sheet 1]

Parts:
C1, C2, C4: 0.1uF; 0805
C3: 10uF; EIA3216
C19, C20: 47pF; 0805
F2: 500mA; 1812
JP4: USB_MICROB_PLUGCONN-11752; USB-B-MICRO-SMD_V03
LED1: RED; CHIP-LED0805
LED2: GREEN; CHIP-LED0805
Q1: 2N7002PW; SOT323
R1, R4, R5, R6: 1k; 0805
R12, R13: 27; 0805
R14, R15: 10k; 0805
U1: FTS31XS-U; SSOP20_L

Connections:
3.3V: C1.2, Q1.1 (G), R14.1, U1.3 (VCCIO), U1.13 (3V3OUT), U1.14 (!RESET); also elsewhere on the board
5V: R1.1, R4.1, R15.1; also elsewhere on the board
DTR: Q1.3 (D), R15.2; also elsewhere on the board
GND: C1.1, C2.1, C3.C (-), C4.2, C19.1, C20.1, JP4.GND1 (GND), JP4.SHIELD1 (SHIELD), JP4.SHIELD2 (SHIELD), JP4.SHIELD3 (SHIELD), U1.6 (GND), U1.16 (GND); also elsewhere on the board
unnamed: LED1.C, U1.17 (CBUS1)
unnamed: LED2.C, U1.10 (CBUS2)
unnamed: LED1.A, R4.2
unnamed: LED2.A, R1.2
unnamed: R5.1, U1.20 (TXD)
unnamed: R6.1, U1.4 (RXD)
unnamed: C20.2, R12.2, U1.12 (USBDM)
unnamed: Q1.2 (S), R14.2, U1.1 (!DTR)
unnamed: C19.2, R13.2, U1.11 (USBDP)
unnamed: JP4.D-1 (D-), R12.1
unnamed: JP4.D+1 (D+), R13.1
unnamed: C4.1, F2.1, JP4.VBUS1 (VCC)
RX: R5.2; also elsewhere on the board
TX: R6.2; also elsewhere on the board
USB_5V: C2.2, C3.A (+), F2.2, U1.15 (VCC); also elsewhere on the board

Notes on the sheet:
Grape Board V1.0

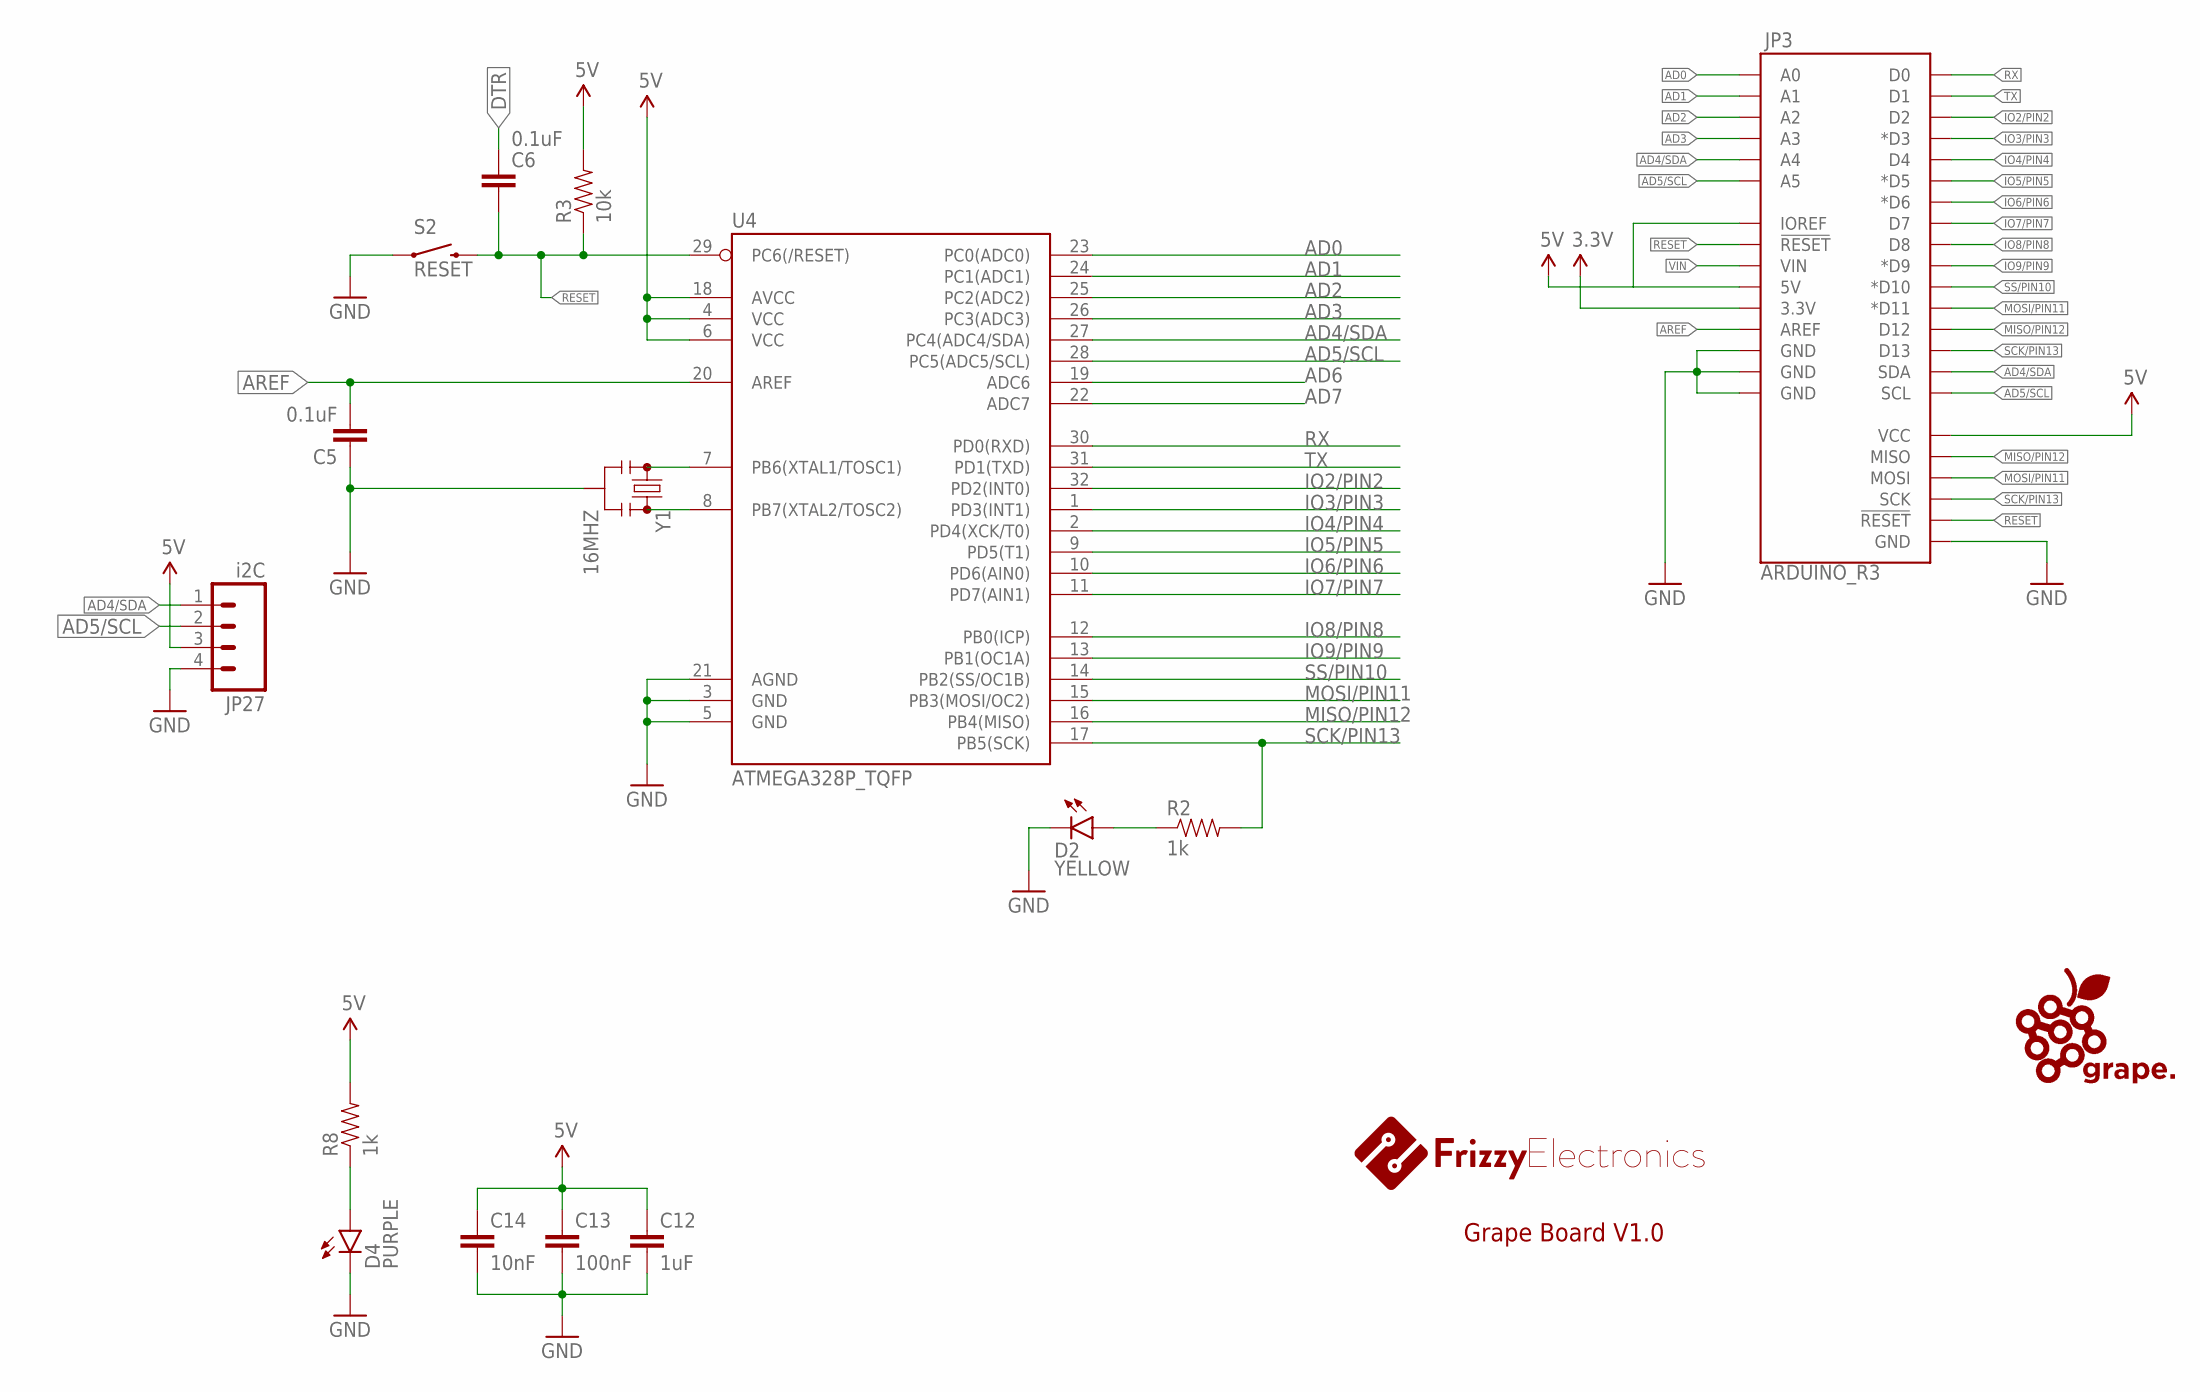
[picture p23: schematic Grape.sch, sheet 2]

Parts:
C5, C6: 0.1uF; 0603-CAP
C12: 1uF; 0603-CAP
C13: 100nF; 0603-CAP
C14: 10nF; 0603-CAP
D2: YELLOW; LED-0603
D4: PURPLE; LED-0603
JP3: ARDUINO_R3
JP27: i2C; JST-4-PTH
R2, R8: 1k; 0805
R3: 10k; 0805
S2: RESET; TACTILE-PTH-SIDEEZ
U4: ATMEGA328P_TQFP; TQFP32-08
Y1: 16MHZ; RESONATOR-SMD

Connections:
3.3V: JP3.3.3V; also elsewhere on the board
5V: C12.1, C13.1, C14.1, JP3.5V, JP3.IOREF, JP3.VCC, JP27.3, R3.2, R8.2, U4.4 (VCC), U4.6 (VCC), U4.18 (AVCC); also elsewhere on the board
AD0: JP3.A0, U4.23 (PC0(ADC0)); also elsewhere on the board
AD1: JP3.A1, U4.24 (PC1(ADC1)); also elsewhere on the board
AD2: JP3.A2, U4.25 (PC2(ADC2)); also elsewhere on the board
AD3: JP3.A3, U4.26 (PC3(ADC3)); also elsewhere on the board
AD4/SDA: JP3.A4, JP3.SDA, JP27.1, U4.27 (PC4(ADC4/SDA)); also elsewhere on the board
AD5/SCL: JP3.A5, JP3.SCL, JP27.2, U4.28 (PC5(ADC5/SCL)); also elsewhere on the board
AD6: U4.19 (ADC6); also elsewhere on the board
AD7: U4.22 (ADC7); also elsewhere on the board
AREF: C5.2, JP3.AREF, U4.20 (AREF)
DTR: C6.1; also elsewhere on the board
GND: C5.1, C12.2, C13.2, C14.2, D2.C, D4.C, JP3.GND@1 (GND), JP3.GND@2 (GND), JP3.GND@3 (GND), JP3.GND@4 (GND), JP27.4, S2.1, U4.3 (GND), U4.5 (GND), U4.21 (AGND), Y1.2; also elsewhere on the board
IO2/PIN2: JP3.D2, U4.32 (PD2(INT0)); also elsewhere on the board
IO3/PIN3: JP3.D3 (*D3), U4.1 (PD3(INT1)); also elsewhere on the board
IO4/PIN4: JP3.D4, U4.2 (PD4(XCK/T0)); also elsewhere on the board
IO5/PIN5: JP3.D5 (*D5), U4.9 (PD5(T1)); also elsewhere on the board
IO6/PIN6: JP3.D6 (*D6), U4.10 (PD6(AIN0)); also elsewhere on the board
IO7/PIN7: JP3.D7, U4.11 (PD7(AIN1)); also elsewhere on the board
IO8/PIN8: JP3.D8, U4.12 (PB0(ICP)); also elsewhere on the board
IO9/PIN9: JP3.D9 (*D9), U4.13 (PB1(OC1A)); also elsewhere on the board
MISO/PIN12: JP3.D12, JP3.MISO, U4.16 (PB4(MISO)); also elsewhere on the board
MOSI/PIN11: JP3.D11 (*D11), JP3.MOSI, U4.15 (PB3(MOSI/OC2)); also elsewhere on the board
unnamed: D2.A, R2.1
unnamed: D4.A, R8.1
unnamed: U4.7 (PB6(XTAL1/TOSC1)), Y1.1
unnamed: U4.8 (PB7(XTAL2/TOSC2)), Y1.3
RESET: C6.2, JP3.RESET@1 (!RESET!), JP3.RESET@2 (!RESET!), R3.1, S2.2, U4.29 (PC6(/RESET))
RX: JP3.D0, U4.30 (PD0(RXD)); also elsewhere on the board
SCK/PIN13: JP3.D13, JP3.SCK, R2.2, U4.17 (PB5(SCK)); also elsewhere on the board
SS/PIN10: JP3.D10 (*D10), U4.14 (PB2(SS/OC1B)); also elsewhere on the board
TX: JP3.D1, U4.31 (PD1(TXD)); also elsewhere on the board
VIN: JP3.VIN; also elsewhere on the board

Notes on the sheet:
Grape Board V1.0

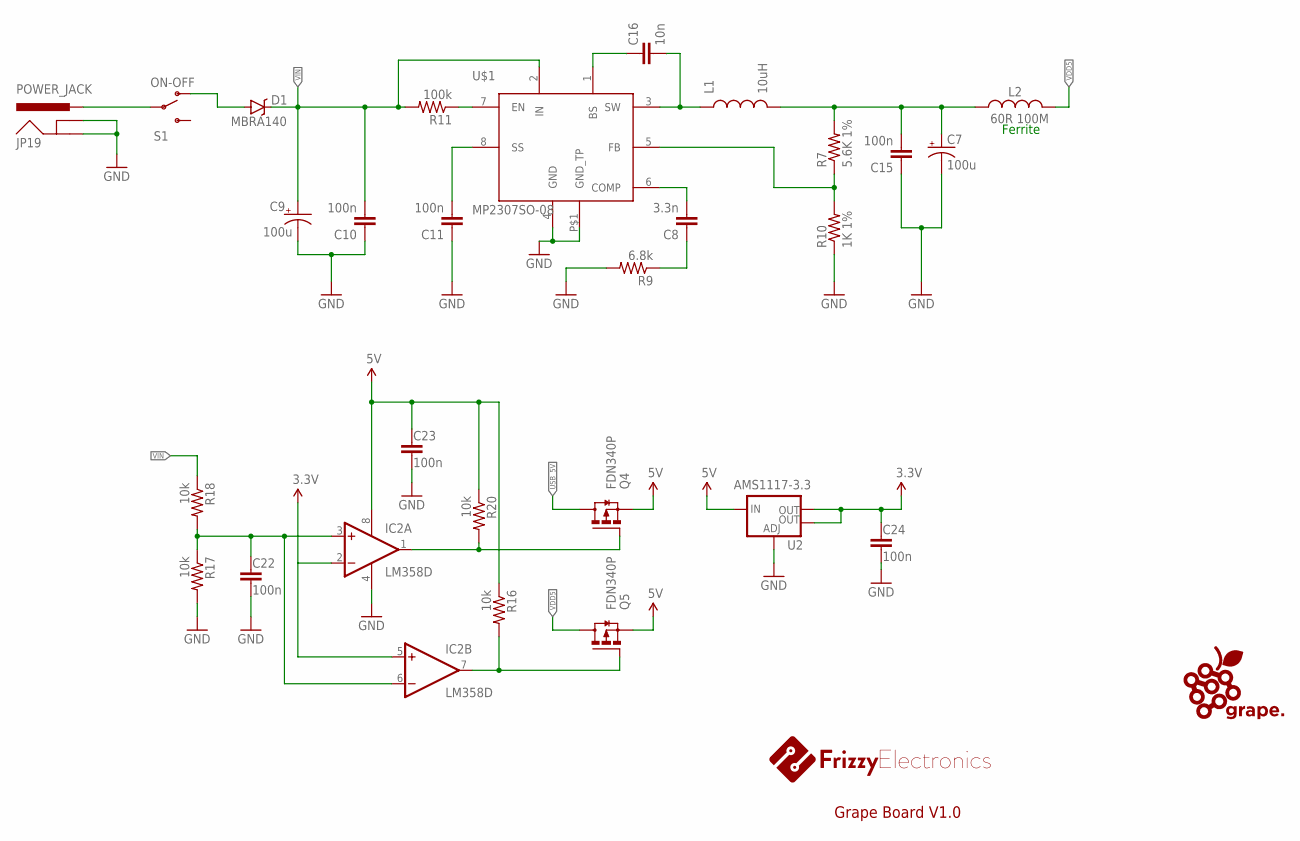
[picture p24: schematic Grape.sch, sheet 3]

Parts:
C7, C9: 100u; PANASONIC_D
C8: 3.3n; 0805
C10, C11, C15, C22, C23, C24: 100n; 0805
C16: 10n; 0805
D1: MBRA140; SMA-DIODE
IC2: LM358D; SO08
JP19: POWER_JACK; POWER_JACK_PTH
L1: 10uH; NPI75C
L2: 60R 100M; 0805
Q4, Q5: FDN340P; SUPER-SOT3
R7: 5.6K 1%; 0805
R9: 6.8k; 0805
R10: 1K 1%; 0805
R11: 100k; 0805
R16, R17, R18, R20: 10k; 0805
S1: ON-OFF; SWITCH-SPST-SMD-A
U2: AMS1117-3.3; SOT223
U$1: MP2307SO-08; SO-08

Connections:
3.3V: C24.1, IC2.2 (-IN), IC2.5 (+IN), U2.2 (OUT), U2.4 (OUT); also elsewhere on the board
5V: C23.1, IC2.8 (V+), Q4.2 (S), Q5.2 (S), R16.1, R20.1, U2.3 (IN); also elsewhere on the board
GND: C7.-, C9.-, C10.1, C11.1, C15.1, C22.2, C23.2, C24.2, IC2.4 (V-), JP19.GND, JP19.GNDBREAK, R9.2, R10.1, R17.2, U2.1 (ADJ), U$1.4 (GND), U$1.P$1 (GND_TP); also elsewhere on the board
unnamed: C8.1, R9.1
unnamed: C8.2, U$1.6 (COMP)
unnamed: R7.1, R10.2, U$1.5 (FB)
unnamed: C16.1, U$1.1 (BS)
unnamed: C16.2, L1.1, U$1.3 (SW)
unnamed: C7.+, C15.2, L1.2, L2.1, R7.2
unnamed: C11.2, U$1.8 (SS)
unnamed: R11.1, U$1.7 (EN)
unnamed: JP19.PWR, S1.2
unnamed: D1.A, S1.1 (O)
unnamed: C22.1, IC2.3 (+IN), IC2.6 (-IN), R17.1, R18.2
unnamed: IC2.7 (OUT), Q5.1 (G), R16.2
unnamed: IC2.1 (OUT), Q4.1 (G), R20.2
USB_5V: Q4.3 (D); also elsewhere on the board
VDD5: L2.2, Q5.3 (D)
VIN: C9.+, C10.2, D1.C, R11.2, R18.1, U$1.2 (IN); also elsewhere on the board

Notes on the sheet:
Ferrite
Grape Board V1.0

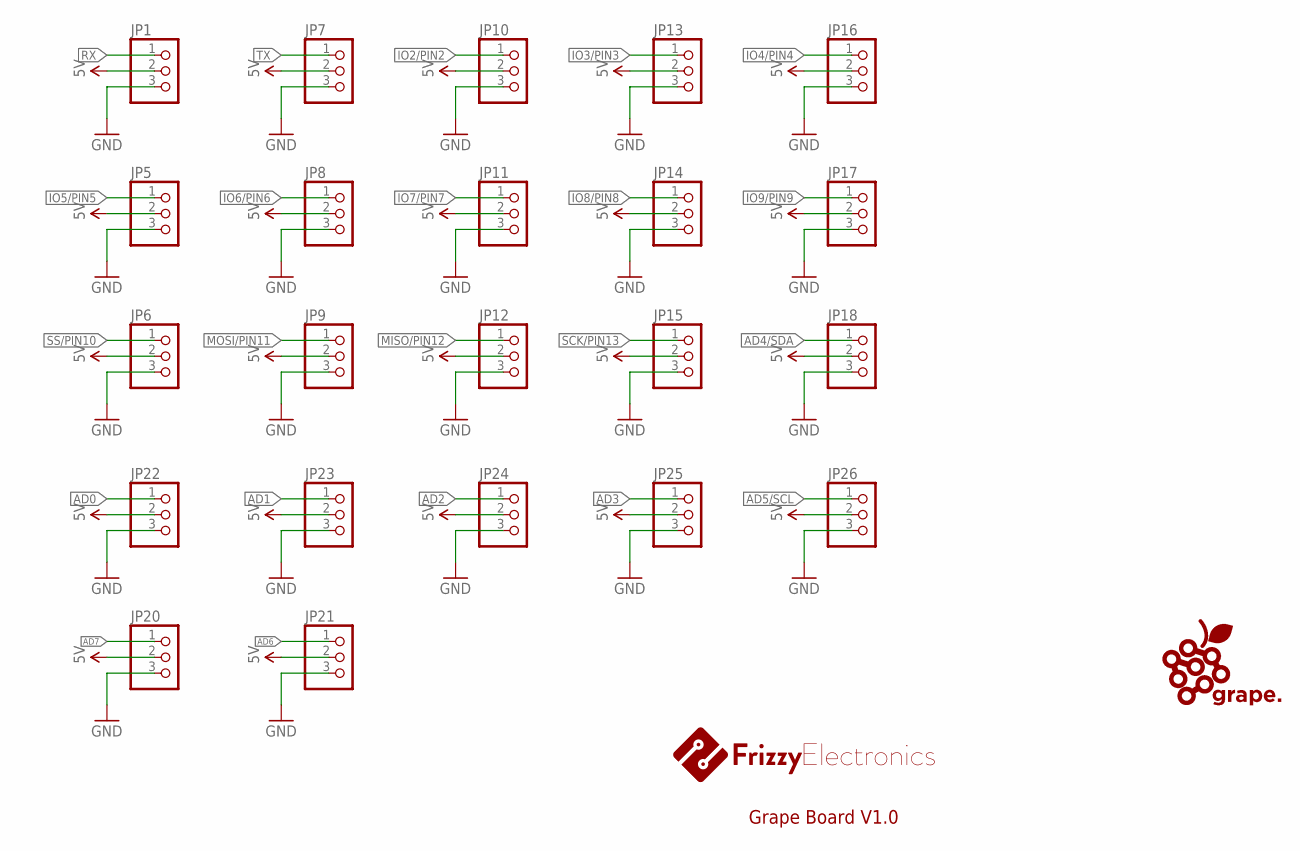
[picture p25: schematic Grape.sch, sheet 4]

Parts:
JP1, JP5, JP6, JP7, JP8, JP9, JP10, JP11, JP12, JP13, JP14, JP15, JP16, JP17, JP18, JP20, JP21, JP22, JP23, JP24, JP25, JP26: PINHD-1X3; 1X03

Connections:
5V: JP1.2, JP5.2, JP6.2, JP7.2, JP8.2, JP9.2, JP10.2, JP11.2, JP12.2, JP13.2, JP14.2, JP15.2, JP16.2, JP17.2, JP18.2, JP20.2, JP21.2, JP22.2, JP23.2, JP24.2, JP25.2, JP26.2; also elsewhere on the board
AD0: JP22.1; also elsewhere on the board
AD1: JP23.1; also elsewhere on the board
AD2: JP24.1; also elsewhere on the board
AD3: JP25.1; also elsewhere on the board
AD4/SDA: JP18.1; also elsewhere on the board
AD5/SCL: JP26.1; also elsewhere on the board
AD6: JP21.1; also elsewhere on the board
AD7: JP20.1; also elsewhere on the board
GND: JP1.3, JP5.3, JP6.3, JP7.3, JP8.3, JP9.3, JP10.3, JP11.3, JP12.3, JP13.3, JP14.3, JP15.3, JP16.3, JP17.3, JP18.3, JP20.3, JP21.3, JP22.3, JP23.3, JP24.3, JP25.3, JP26.3; also elsewhere on the board
IO2/PIN2: JP10.1; also elsewhere on the board
IO3/PIN3: JP13.1; also elsewhere on the board
IO4/PIN4: JP16.1; also elsewhere on the board
IO5/PIN5: JP5.1; also elsewhere on the board
IO6/PIN6: JP8.1; also elsewhere on the board
IO7/PIN7: JP11.1; also elsewhere on the board
IO8/PIN8: JP14.1; also elsewhere on the board
IO9/PIN9: JP17.1; also elsewhere on the board
MISO/PIN12: JP12.1; also elsewhere on the board
MOSI/PIN11: JP9.1; also elsewhere on the board
RX: JP1.1; also elsewhere on the board
SCK/PIN13: JP15.1; also elsewhere on the board
SS/PIN10: JP6.1; also elsewhere on the board
TX: JP7.1; also elsewhere on the board

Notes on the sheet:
Grape Board V1.0

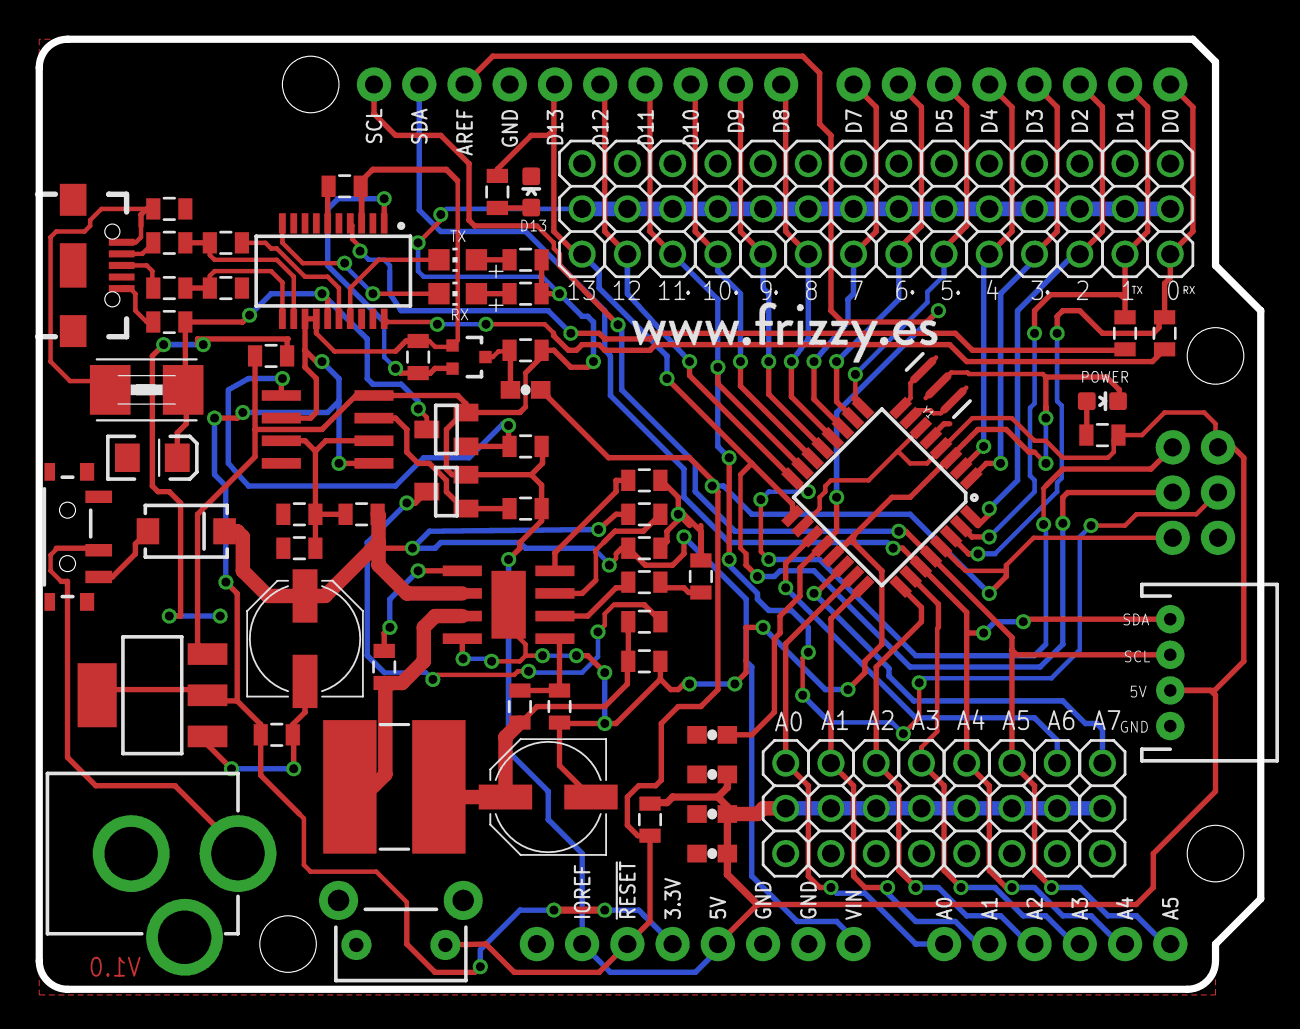
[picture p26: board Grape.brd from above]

Board: 2 copper layers, 68.6 x 53.3 mm, 86 parts (1 on the bottom side), 60 nets.

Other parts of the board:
U$4: OSHW-LOGO-M

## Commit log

2016-08-02 Add files via upload
    Version 1.0
    [Placa frizzy.brd, Placa frizzy.sch, Plantilla Arduino Uno.brd]
2016-11-19 Ultima version mandada a fabrica
    [Placa frizzy.brd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]
2017-01-09 Vias Tapadas, USB cambiado, TX RX añadido
    se ha reparado tambien la alimentacion de 5V
    [Placa frizzy.brd, Placa frizzy.sch]
2017-07-17 Ficheros de diseño añadidos
    [Grape.brd, Grape.sch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]
2017-07-17 Limpieza de archivos basura
    [Placa frizzy.xlsx]
2017-07-17 Iniciando la documentacion
2017-07-17 Readme añadido
    [Placa frizzy.GBL, Placa frizzy.GBO, Placa frizzy.GBS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]
2018-01-14 Comenzando la migracion a kicad, esquema y hojas creadas
    [Grape.kicad_pcb, Grape.sch, Microcontroller.sch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]
2018-01-14 Primera pagina terminada
    [usb_communication.sch]
2018-01-14 Microcontrolador añadido
    [Microcontroller.sch, Sockets_and_connectors.sch]
2018-01-14 Alimentacion comenzada
    [Grape.sch, Microcontroller.sch, Power.sch]
2018-01-15 Alimentacion terminada
    [Microcontroller.sch, Power.sch, Sockets_and_connectors.sch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]
2018-01-15 Esquema terminado y ERC pasado
    [Grape.sch, Microcontroller.sch, Power.sch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]
2018-01-15 cvpcb terminado
    [Microcontroller.sch, Power.sch, Sockets_and_connectors.sch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]
2018-01-15 Semiconductores colocados en placa y 3D añadido
    [Grape.dxf, Grape2.dxf, Grape3.dxf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]
2018-01-17 3D terminado
    [Grape.kicad_pcb]
2018-01-17 Comenzado el enrutado
    [Grape.kicad_pcb]
2018-01-25 copia de seguridad
    [Grape.kicad_pcb]
2018-01-29 Enrutando la placa
    [Grape.kicad_pcb]
2018-01-29 enrutado completo
    [Grape.kicad_pcb]
2018-01-29 empezando con la serigrafia
    [Grape.kicad_pcb]
2018-01-30 Avanzando con la serigrafia
    [Grape.dxf, Grape.kicad_pcb]
2018-02-04 Serigrafia web añadida
    [Grape.kicad_pcb]
2018-02-04 Usb cambiado
    [Grape.kicad_pcb, _saved_Microcontroller.sch]
2018-05-06 Cambiando el árbol de carpetas
    [Grape.csv, Grape.kicad_pcb, Grape.sch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]
2018-05-06 Carpeta limpada de .mod's
2018-05-06 3D enlazado y arbol de carpetas terminado
    [Grape.kicad_pcb]
2018-05-13 Valores cambiados
    [Componentes.xlsx, Grape.csv, Grape.kicad_pcb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]
2018-06-08 Añadida serigrafia en PWM pins
    [Componentes.xlsx, Grape.kicad_pcb]
2018-06-08 Gerbers generados y mandado a fabrica para prueba
    Fabricado con JLCPCB a 1.2mm y sin merge
    [Grape.kicad_pcb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]
2018-07-14 Re-rellenado el plano de masa
    [Grape.kicad_pcb]
2018-07-15 Gerbers exportados
    [Grape.kicad_pcb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]

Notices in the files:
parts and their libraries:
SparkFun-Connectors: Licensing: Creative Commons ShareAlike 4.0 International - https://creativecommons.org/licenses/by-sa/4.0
